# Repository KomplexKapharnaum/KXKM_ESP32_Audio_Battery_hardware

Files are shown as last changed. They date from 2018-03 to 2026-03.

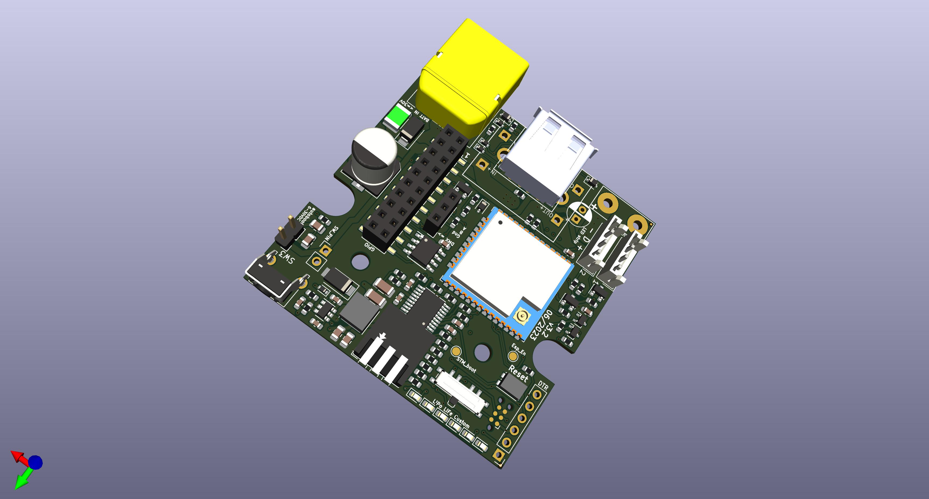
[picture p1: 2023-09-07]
Base_board/in-progress/KXKM_ESP32_battery_management_board.jpg

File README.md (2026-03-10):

# KXKM_ESP32_Audio_Battery_hardware

## Overview
Hardware workspace for the KXKM ESP32 battery + audio platform.
The repository groups KiCad design files for battery management and remote control boards.

## Installation
Prerequisites:
- KiCad 7/8 for schematic/project edits
- Git LFS is not required for the current tracked files

## Usage
Typical workflow:
1. Open the board project under `Base_board/v3.2/`.
2. Review schematic updates in `*.kicad_sch`.
3. Export manufacturing artifacts (Gerber/BOM) from KiCad when needed.

## Architecture
Main areas:
- `Base_board/`: battery management board revisions
- `Audio_board/`: audio-related board files
- `Remote_control_board/`: remote control board symbols/project config

## Testing & Quality
Recommended checks before commit:
- KiCad ERC/DRC on edited projects
- Diff review on `.kicad_sch`/`.kicad_pro` changes
- Ensure no local artifacts are tracked (`.DS_Store`, `*-backups/*.zip`)

## Performance & Optimization
Optimization focus:
- Keep schematic commits isolated from hygiene/meta commits
- Reduce noisy diffs by excluding generated/local backup files

## Security
Security notes:
- Avoid committing private manufacturing or supplier credentials
- Keep BOM/vendor metadata reviewable in plain text when possible

## Roadmap
Near-term:
- Finalize battery board v3.2 review cycle
- Validate remote control symbol table consistency

<!-- CHANTIER:AUDIT START -->
## Audit & Execution Plan (2026-03-10)

### Snapshot
- Priority: `P2`
- Tech profile: `other`
- Workflows: `yes`
- Tests: `yes`
- Debt markers: `0`
- Source files: `0`

### Corrections Prioritaires
- [ ] Optimisation ciblée perf/maintenabilité
- [ ] Ajouter/fiabiliser les commandes de vérification automatiques.
- [ ] Clore les points bloquants avant optimisation avancée.

### Optimisation
- [ ] Identifier le hotspot principal et mesurer avant/après.
- [ ] Réduire la complexité des modules les plus touchés.

### Mémoire chantier
- Control plane: `/Users/electron/.codex/memories/electron_rare_chantier`
- Repo card: `/Users/electron/.codex/memories/electron_rare_chantier/REPOS/KXKM_ESP32_Audio_Battery_hardware.md`

<!-- CHANTIER:AUDIT END -->

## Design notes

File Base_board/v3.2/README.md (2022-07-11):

To Panelize:
Install Kikit (at least the module, no need to install in kicad via PCM)

> kikit panelize -p panelizing_config.json KXKM_ESP32_battery_management_board.kicad_pcb PANEL/panel.kicad_pcb

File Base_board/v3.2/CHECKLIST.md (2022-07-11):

# Procédure prod 05/19
* Contrôle visuel dessus & dessous (polarité IC, diodes)
* Alim 6V 0.05A => check 3.3V à l'appui sur le bouton.
* Alim 24V 0.5A + constant current load => Flash STM32_HW_Test et exécuter tous les tests
//!!!!! CHANGER LES SEUILS !!
* Alim 6V 0.5A (ou injecte 3.3V direct) => Flash STM32 KXKM Batt Monitoring + assign ID + marquage
*       Flash ESP32 HW Test

# 23/07/19 troubleshooting prog. ESP
* =>> erreur Warning: Could not auto-detect Flash size (FlashID=0xffffff, SizeID=0xff), defaulting to 4MB : vérifier que IO6-IO11 ne sont pas en CC ; vérifier IO12 LOW (https://github.com/espressif/esptool/issues/263)
    Un bon coup de chaud sur l'ESP32 jusquà ce qu'il flotte et c'est reparti...

* Vérifier RX conn prog <-> ESP => rés. 1k
* Vérifier TX conn prog <-> ESP => connectés
* vérifier TX, RX pas en CC / pas en CC GND, 3.3V
* vérifier ESP32 BOOT, EN pas en CC GND, 3.3V
* vérifier 3.3V, GND ESP
* lancer prog et vérifier qu'il y a une pulse nég sur BOOT, nég sur EN

* Pas de court circuit entre - et + BATT, +3.3V
* Alimenter par Power In sous 6V (limite 100mA)
* Appuyer sur SW3 et vérifier la présence 3.3V tant qu'on tient SW3 appuyé.

# ESP32
* maintenir SW3 appuyé et brancher l'USB série /!\ vérifier CH430...
* insérer carte SD test
* Vérifier programmation et autoreset
* Flasher ESP32_HW_Test (/!\ pour la 1e programmation il faut peut être y aller à 115200 bps)
* Vérifier carte SD
* Vérifier sortie son

# STM32
* mettre sélecteur de batterie sur Custom
* brancher JLink device stm32f030f4 et vérifier que ça connecte bien
* Flasher STM32_HW_Test
* Vérifier jauge LED, détection bouton poussoir, sélecteur type batterie
* Vérifier activation sortie principale (+ mesure courant ?)
* Vérifier mesure tension batterie
* Vérifier activation ESP32 et communication
* Vérifier maintien 3.3V et coupure

# Programmation STM32
## Environnement
* Installer https://github.com/stm32duino/wiki/wiki/Getting-Started#boards-manager-concept > installe les outils, l'environnement etc pour STM32
* Récupérer le dépot git et pointer Arduino (Préférences > Emplacement du carnet de croquis)
* Sélectionner Type de carte : KXKM_STM32F030

## Upload
* Croquis > Exporter les binaires compilées
* mettre sélecteur de batterie sur Custom
* JlinkExe
** connect
** device stm32f030f4
** loadfile /home/tom/Nextcloud/KXKM/Module_Immobiles/firmware/Arduino/STM32_Blink/STM32_Blink.ino.KXKM_STM32F030F4.hex
** loadfile /home/tom/Nextcloud/KXKM/Module_Immobiles/firmware/Arduino/STM32_HW_test/STM32_HW_test.ino.KXKM_STM32F030F4.hex
** r
** g
* ou bien :
  cd <sketchName>
	JLinkExe -commanderscript STM32_flash.jlink

# 27/03/18 Tests
* régul 3.3V OK => 1A @6V IN, 800mA @ 25V IN
* activation régul par bouton OK
* programmation STM32 OK
* maintien et coupure du régul par STM32 OK
* ESP32 enable par STM32 OK
* ESP32 auto reset et programmation OK
* Load switch enable OK
* détection push button OK
* LED OK
* Sélecteur batterie OK
* communication ESP32 OK
* ESP32 carte SD OK
* ESP32 DAC OK
* emplacement ampli OK
* Load switch current à tester

# NOTES
* si SDA est tiré à la masse par l'ESP32 alors la programmation physique est impossible (drive BOOT par Q3B qui drive DTR par Q1A). Solution : Tirer ESP32_EN à la masse manuellement... et relacher au bon moment (alors que esptool dit Connecting...). Possible de le faire par le STM32 au reset ??? écoute sur le TX et active ESP32_EN au bon moment ?

# Troubleshooting
## Prog STM32
* Vérifier que le switch est bien en pos "Custom"

## carte SD
* Vérifier les soudures sur l'ESP

## Prog ESP32
* Resouder RN1, RN2
* Vérifier que l'ESP boote quand démarré par le STM32

## ESP32 always on
* Vérfier RN1

## Detection BP
* Vérifier diode Zener

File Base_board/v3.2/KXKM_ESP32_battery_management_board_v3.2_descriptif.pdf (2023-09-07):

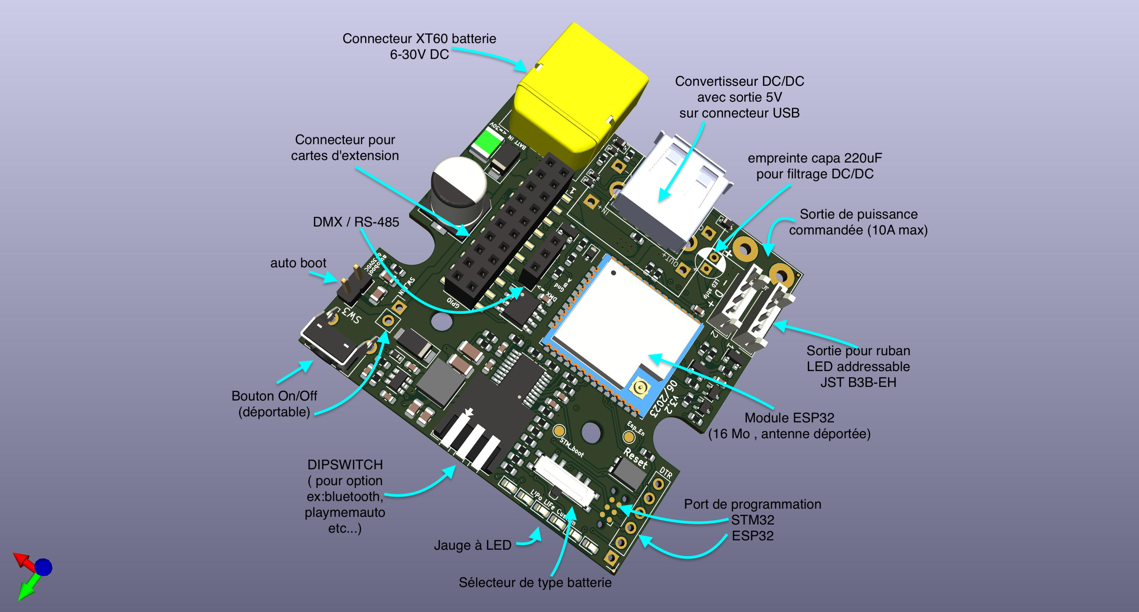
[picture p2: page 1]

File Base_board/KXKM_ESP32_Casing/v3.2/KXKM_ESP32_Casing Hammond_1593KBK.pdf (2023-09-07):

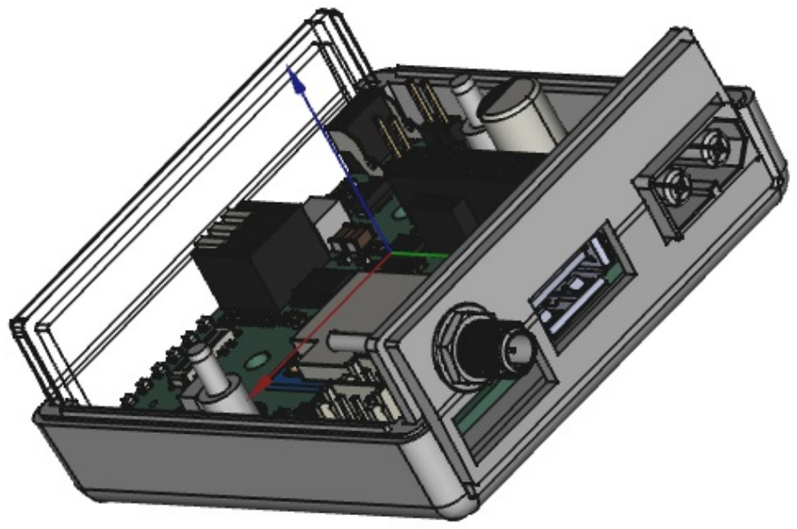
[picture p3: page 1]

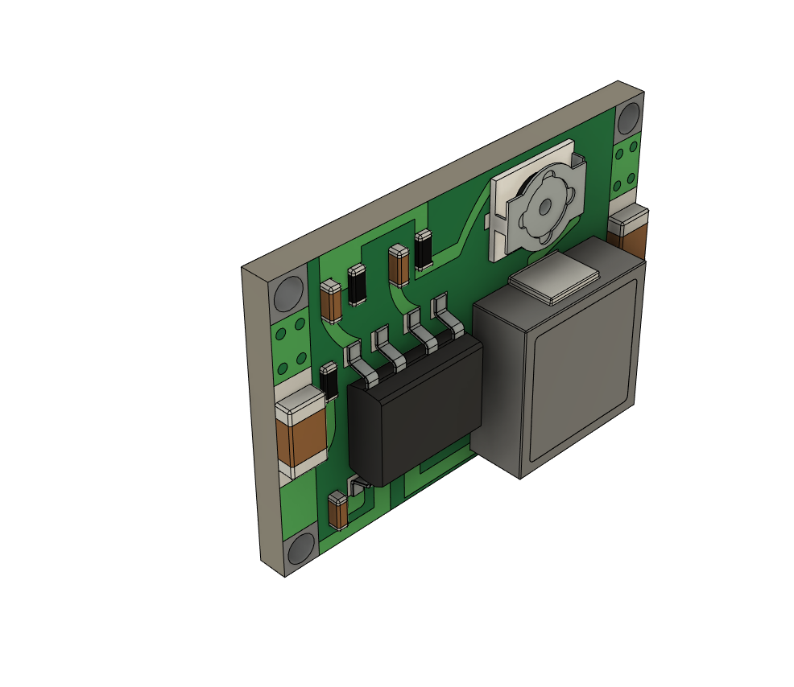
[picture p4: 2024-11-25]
Base_board/v3.2/mini-360-mp2307-1/MIni_1.png

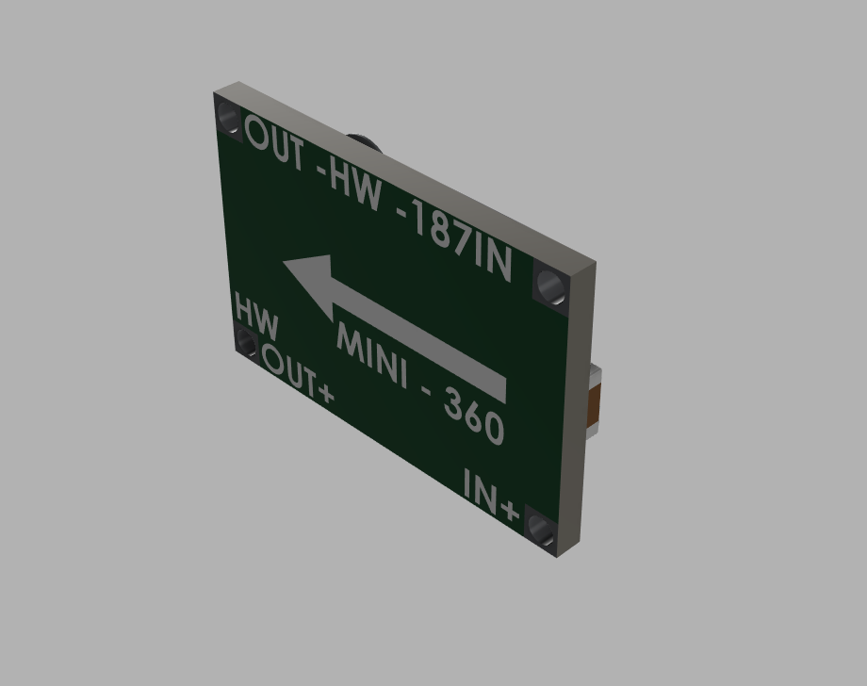
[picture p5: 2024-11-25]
Base_board/v3.2/mini-360-mp2307-1/MIni_4.png

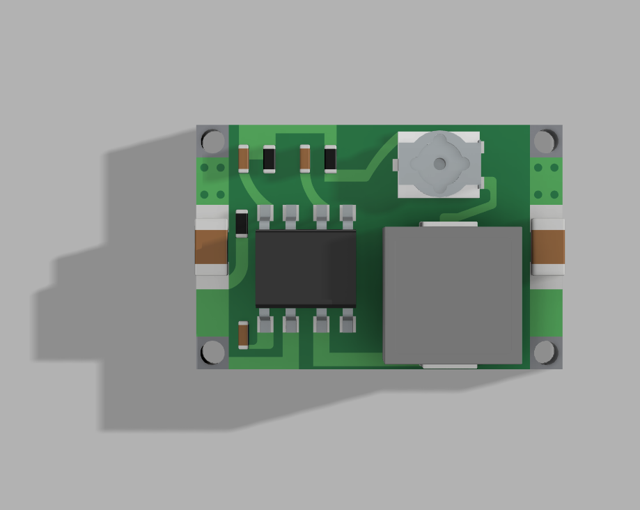
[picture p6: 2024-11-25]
Base_board/v3.2/mini-360-mp2307-1/MIni-2.png

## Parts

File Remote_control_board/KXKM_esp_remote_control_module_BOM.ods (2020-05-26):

Source: | C:\Users\utilisateur\Documents\KXKM\Git\KXKM_ESP32_Audio_Battery_hardware\Remote_control_board\KXKM_esp_remote_control_module.sch
Date: | 26/02/2020 17:42:19
Tool: | Eeschema (5.0.0)
Generator: | C:\Program Files\KiCad\bin\scripting\plugins/bom_csv_grouped_by_value.py
Component Count: | 21
Individual Components:
Item | Qty per board | Reference(s) | Value | Link | LibPart | Footprint
Capacitor | 2 | C1, C3 | 47n | https://fr.farnell.com/vishay/k473k20x7rh53h5/condensateur-47nf-100v-10-x7r/dp/3549756 | Device:C_Small | Capacitor_THT:C_Disc_D4.3mm_W1.9mm_P5.00mm
Capacitor | 1 | C2 | 4.7n | https://fr.farnell.com/vishay/k472k10x7rf5uh5/condensateur-4700pf-50v-10-x7r/dp/2860131 | Device:C_Small | Capacitor_THT:C_Disc_D4.3mm_W1.9mm_P5.00mm
Capacitor | 1 | C4 | 0.1u | https://fr.farnell.com/vishay/k104k15x7rf53l2/condensateur-0-1-f-50v-10-x7r/dp/1141775 | Device:C_Small | Capacitor_THT:C_Disc_D3.0mm_W1.6mm_P2.50mm
Capacitor | 1 | C5 | 0.33u | https://fr.farnell.com/multicomp/mc0805b334k500a5-08mm/condensateur-0-33-f-50v-10-x7r/dp/2309021 | Device:C_Small | Capacitor_THT:C_Disc_D4.3mm_W1.9mm_P5.00mm
LED | 1 | D1 | LED | Std – Not mounted | Device:LED | LED_SMD:LED_0805_2012Metric_Pad1.15x1.40mm_HandSolder
Pin header | 2 | J1, J6 | Conn_01x03 | Not mounted | Connector_Generic:Conn_01x03 | Connector_PinHeader_2.54mm:PinHeader_1x03_P2.54mm_Vertical
Pin header | 1 | J2 | Conn_02x10_Odd_Even | https://fr.farnell.com/harwin/m20-8751042/conn-header-20-voies-2-rangees/dp/3225960 | Connector_Generic:Conn_02x10_Odd_Even | Connector_PinHeader_2.54mm:PinHeader_2x10_P2.54mm_Vertical_SMD
Pin header | 1 | J3 | Conn_02x10_Odd_Even | Not mounted / In stock | Connector_Generic:Conn_02x10_Odd_Even | Connector_PinSocket_2.54mm:PinSocket_2x10_P2.54mm_Vertical_SMD
Pin header | 2 | J4, J5 | GPIO_conn | Not mounted / In stock | Connector_Generic:Conn_01x10 | Connector_PinHeader_2.54mm:PinHeader_1x10_P2.54mm_Vertical
Solder jumper | 2 | JP1, JP2 | Solder_Open | ~ | Jumper:SolderJumper_2_Open | Jumper:SolderJumper-2_P1.3mm_Open_TrianglePad1.0x1.5mm
Resistor | 1 | R1 | 22k | https://fr.farnell.com/multicomp/mcre000053/resistance-couche-carbon-125mw/dp/1700255 | Device:R | Resistor_THT:R_Axial_DIN0204_L3.6mm_D1.6mm_P5.08mm_Horizontal
Resistor | 1 | R2 | 220 | Std – Not mounted | Device:R | Resistor_SMD:R_0805_2012Metric_Pad1.15x1.40mm_HandSolder
Switch SPDT | 1 | SW1 | SW_SPDT | https://fr.farnell.com/nidec-copal/mfs101d-10-z/commut-glissiere-spdt-0-3a-30vdc/dp/2854841 | Switch:SW_SPDT | KXKM_esp_remote:Sw_MFS101D-10_1x03_P2.00mm
Switch push | 1 | SW2 | SW_Push | https://fr.farnell.com/c-k-components/pts645vh58-2lfs/commutateur-spst-0-05a-12vdc-tht/dp/2320088 | Switch:SW_Push | Button_Switch_THT:SW_Tactile_SPST_Angled_PTS645Vx58-2LFS
Current Sensor | 1 | U1 | HO10P-P-SP33 | https://fr.farnell.com/lem/ho-10-p-sp33/capteur-courant-10a-3-14vdc-3/dp/2664205?st=HO10P | KXKM_esp_remote_control_module:HO10P-P-SP33 | KXKM_esp_remote:HO10PSP33
I2C extender | 1 | U3 | MCP23017_SP | https://fr.farnell.com/microchip/mcp23017-e-sp/16-bit-expander-i-o-i2c-i-f/dp/1332088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 | :MCP23017_SP-Interface_Expansion | Package_DIP:DIP-28_W7.62mm
Voltage regulator | 1 | U4 | L78L33_TO92 | https://fr.farnell.com/stmicroelectronics/l78l33abz-ap/regulateur-lineaire-3-3v-0-1a/dp/2849743 | Regulator_Linear:L78L33_TO92 | Package_TO_SOT_THT:TO-92_Inline
Additionnal component for testing
Current Sensor | 1 | CJMCU758 | CJMCU758 | https://fr.aliexpress.com/item/32790187550.html?src=google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

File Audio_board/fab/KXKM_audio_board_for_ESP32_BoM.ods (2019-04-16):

KXKM – Audio DAC for ESP32 module
v1.0 – 04/2019
Reference | Qty | Value | Package | Link CN | Price (Qty 100) | Link Farnell | Price | Link RS | Price | Link Mouser | Commande production | Price | Link DGK | Price
C1 | 1 | DNP/0.1uF | C_0603_1608Metric | std
C10,C9 | 2 | 2.2uF,25V | C_0603_1608Metric | https://lcsc.com/product-detail/Multilayer-Ceramic-Capacitors-MLCC-SMD-SMT_muRata_GRM188R61E225KA12D_2-2uF-225-10-25V_C77047.html | 0,0254
C13,C12 | 2 | 2.2nF/C0G | C_0603_1608Metric | https://lcsc.com/product-detail/Multilayer-Ceramic-Capacitors-MLCC-SMD-SMT_2-2nF-222-5-50V_C107043.html | 0,0243
C14 | 1 | 10uF,50V | C_1206_3216Metric | https://lcsc.com/product-detail/Multilayer-Ceramic-Capacitors-MLCC-SMD-SMT_SAMSUNG_CL31A106KBHNNNE_10uF-106-10-50V_C13585.html | 0,0668
C2 | 1 | DNP/10nF | C_0603_1608Metric | std
C3,C5 | 2 | 10uF,10V | C_0805_2012Metric | std
C4 | 1 | 1uF | C_0603_1608Metric | std
C8,C11,C7,C6 | 4 | 0.1uF | C_0603_1608Metric | std
FB1 | 1 | 60R@100M | L_0805_2012Metric | std
J1 | 1 | Conn_02x10_Odd_Even | PinHeader_2x10_P2.54mm_Vertical_SMD | TODO Aliexpress
J2 | 1 | AudioJack2_Ground | Jack_3.5mm_stereo_PJ-313D | https://lcsc.com/product-detail/Audio-Connectors_Straight-headphone-jack_C18167.html | 0,049
J3 | 1 | Conn_02x10_Odd_Even | PinSocket_2x10_P2.54mm_Vertical_SMD | DNP
R2,R1 | 2 | 470R,1% | R_0603_1608Metric | std
R3,R4 | 2 | 10k | R_0603_1608Metric | std
U1 | 1 | DNP/TPS79133DBVR | SOT-23-5
U2 | 1 | PCM5121 | TSSOP-28_4.4x9.7mm_P0.65mm |  |  |  |  |  |  | https://www.mouser.fr/ProductDetail/Texas-Instruments/PCM5121PWR | 2,24
U3 | 1 | Audio_amp_OEP30W | Audio_amp_OEP30W
U4 | 1 | Audio_amp_OEP30Wx2 | Audio_amp_OEP30Wx2

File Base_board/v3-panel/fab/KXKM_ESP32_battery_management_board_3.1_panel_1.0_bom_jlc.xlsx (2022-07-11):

Comment | Designator | Footprint | JLCPCB Part
BC847W | B2-Q2,B4-Q1,B8-Q1,B5-Q2,B3-Q1,B7-Q2,B1-Q2,B4-Q2,B6-Q2,B0-Q2,B1-Q1,B8-Q2,B2-Q1,B5-Q1,B0-Q1,B7-Q1,B6-Q1,B3-Q2 | SOT-323_SC-70 | C75568
SW_SP3T | B1-SW4,B4-SW4,B7-SW4,B2-SW4,B5-SW4,B6-SW4,B0-SW4,B3-SW4,B8-SW4 | SW_SP3T_PCM13 | C160878
Conn_02x10_Odd_Even | B7-J3,B5-J3,B4-J3,B0-J3,B1-J3,B6-J3,B2-J3,B3-J3,B8-J3 | PinSocket_2x10_P2.54mm_Vertical_SMD | C59981
Green | B2-D7,B0-D7,B2-D5,B3-D5,B3-D6,B1-D5,B2-D6,B5-D5,B4-D6,B0-D6,B7-D5,B8-D7,B8-D5,B1-D6,B7-D6,B6-D5,B8-D6,B5-D7,B1-D7,B6-D6,B3-D7,B7-D7,B4-D7,B5-D6,B0-D5,B4-D5,B6-D7 | LED_0603_1608Metric | C72043
470R | B1-R28,B4-R8,B4-R28,B6-R8,B3-R8,B5-R8,B8-R8,B0-R8,B1-R8,B7-R8,B2-R8,B8-R28,B6-R28,B3-R28,B5-R28,B2-R28,B7-R28,B0-R28 | R_0603_1608Metric | C23179
10k | B2-R3,B8-R3,B1-R19,B5-R6,B5-R37,B5-R18,B6-R6,B8-R6,B6-R17,B1-R20,B6-R11,B6-R35,B7-R37,B2-R37,B0-R35,B2-R19,B8-R18,B4-R11,B2-R6,B3-R21,B4-R6,B3-R18,B6-R4,B7-R17,B0-R5,B0-R11,B3-R5,B7-R21,B7-R11,B4-R4,B0-R4,B8-R20,B7-R3,B8-R37,B5-R11,B0-R18,B7-R6,B4-R3,B6-R3,B1-R11,B0-R21,B3-R20,B4-R18,B1-R6,B4-R35,B3-R3,B7-R19,B6-R5,B5-R5,B7-R18,B8-R4,B1-R17,B3-R37,B5-R20,B2-R11,B1-R5,B3-R19,B2-R17,B0-R3,B4-R5,B0-R37,B3-R6,B1-R37,B4-R20,B1-R21,B3-R4,B2-R4,B2-R35,B4-R17,B4-R37,B7-R4,B7-R35,B0-R19,B3-R35,B5-R3,B5-R35,B2-R20,B6-R21,B8-R21,B8-R19,B3-R11,B2-R21,B7-R20,B8-R17,B4-R19,B3-R17,B1-R35,B0-R20,B1-R3,B1-R18,B5-R19,B8-R11,B7-R5,B5-R17,B6-R19,B8-R35,B2-R18,B6-R20,B1-R4,B5-R21,B6-R37,B0-R17,B4-R21,B0-R6,B6-R18,B5-R4,B2-R5,B8-R5 | R_0603_1608Metric | C25804
100uF,50V | B7-C6,B2-C6,B0-C6,B1-C6,B3-C6,B4-C6,B8-C6,B6-C6,B5-C6 | CP_Elec_8x10 | C97812
SW_Push | B4-SW1,B0-SW1,B7-SW1,B1-SW1,B6-SW1,B3-SW1,B2-SW1,B5-SW1,B8-SW1 | SW_SPST_KMR2 | C128941
0R | B5-R31,B6-R31,B7-R31,B8-R31,B2-R31,B3-R31,B1-R31,B4-R31,B0-R31 | R_0603_1608Metric | C21189
1k | B6-R23,B7-R23,B5-R2,B6-R2,B3-R2,B3-R23,B2-R23,B2-R2,B7-R2,B8-R2,B8-R23,B0-R23,B1-R2,B5-R23,B4-R2,B4-R23,B0-R2,B1-R23 | R_0603_1608Metric | C21190
22k | B2-R38,B1-R33,B8-R38,B3-R36,B1-R38,B5-R33,B0-R38,B0-R33,B8-R33,B3-R33,B4-R38,B1-R36,B0-R36,B3-R34,B4-R33,B5-R38,B4-R36,B6-R33,B3-R38,B8-R34,B2-R33,B5-R36,B7-R38,B7-R33,B2-R34,B8-R36,B6-R38,B0-R34,B6-R36,B4-R34,B5-R34,B7-R36,B7-R34,B1-R34,B2-R36,B6-R34 | R_0603_1608Metric | C31850
Yellow | B8-D8,B6-D8,B1-D9,B7-D9,B8-D9,B2-D8,B1-D8,B0-D8,B3-D9,B2-D9,B5-D9,B6-D9,B0-D9,B3-D8,B7-D8,B4-D8,B4-D9,B5-D8 | LED_0603_1608Metric | C72038
MCP16331T-E/CH | B3-U3,B7-U3,B1-U3,B8-U3,B2-U3,B0-U3,B4-U3,B6-U3,B5-U3 | SOT-23-6 | C105695
SW_DIP_x03 | B7-SW2,B6-SW2,B0-SW2,B5-SW2,B4-SW2,B1-SW2,B2-SW2,B3-SW2,B8-SW2 | SW_DIP_SPSTx03_Piano_CTS_Series194-3MSTN_W7.62mm_P2.54mm | C319070
31.6k/1% | B6-R16,B0-R16,B4-R16,B3-R16,B1-R16,B1-R9,B4-R9,B8-R16,B5-R16,B6-R9,B5-R9,B7-R9,B3-R9,B2-R16,B7-R16,B2-R9,B0-R9,B8-R9 | R_0603_1608Metric | C25967
Conn_01x02 | B0-J5,B8-J5,B4-J5,B1-J5,B5-J5,B6-J5,B3-J5,B2-J5,B7-J5 | PinHeader_1x02_P2.54mm_Vertical | C124375
1nF | B6-C21,B5-C21,B2-C21,B1-C21,B7-C21,B3-C21,B0-C21,B8-C21,B4-C21 | C_0603_1608Metric | C1588
10k/1% | B5-R1,B8-R1,B5-R10,B2-R10,B3-R10,B6-R10,B0-R1,B7-R10,B0-R10,B6-R1,B4-R10,B4-R1,B1-R1,B1-R10,B2-R1,B3-R1,B8-R10,B7-R1 | R_0603_1608Metric | C25804
15uH,1.5A | B3-L1,B4-L1,B1-L1,B7-L1,B8-L1,B5-L1,B6-L1,B0-L1,B2-L1 | L_Taiyo-Yuden_NR-50xx | C206232
10uF/50V | B5-C4,B8-C4,B3-C5,B2-C4,B2-C5,B4-C5,B0-C5,B0-C4,B7-C5,B5-C5,B4-C4,B7-C4,B6-C5,B8-C5,B1-C5,B1-C4,B6-C4,B3-C4 | C_1206_3216Metric | C13585
0.5A/30V | B8-F1,B2-F1,B7-F1,B5-F1,B0-F1,B3-F1,B6-F1,B4-F1,B1-F1 | Fuse_1812_4532Metric | C269128
270k/1% | B7-R15,B6-R15,B2-R15,B5-R15,B1-R15,B0-R15,B3-R15,B4-R15,B8-R15 | R_0603_1608Metric | C22965
10uF | B6-C9,B5-C9,B2-C9,B4-C10,B7-C10,B1-C10,B0-C9,B8-C10,B3-C10,B2-C10,B8-C9,B6-C10,B4-C9,B1-C9,B5-C10,B0-C10,B3-C9,B7-C9 | C_0805_2012Metric | C440198
Conn_01x06 | B1-J1,B8-J1,B5-J1,B6-J1,B2-J1,B4-J1,B0-J1,B7-J1,B3-J1 | PinHeader_1x06_P2.54mm_Vertical | C37208
1N4148WT | B5-D1,B4-D12,B7-D15,B8-D1,B0-D1,B2-D15,B0-D4,B4-D4,B8-D12,B5-D4,B1-D15,B3-D1,B3-D4,B1-D4,B1-D12,B0-D15,B4-D15,B3-D15,B6-D12,B7-D1,B8-D4,B8-D15,B2-D4,B1-D1,B6-D15,B5-D12,B6-D1,B7-D12,B7-D4,B3-D12,B4-D1,B0-D12,B2-D12,B6-D4,B5-D15,B2-D1 | D_SOD-523 | C68948
0.1uF | B4-C2,B1-C7,B0-C22,B8-C23,B5-C23,B4-C7,B2-C2,B5-C22,B1-C23,B1-C24,B2-C7,B5-C2,B3-C23,B4-C24,B2-C3,B3-C2,B2-C24,B0-C7,B0-C23,B6-C24,B0-C3,B7-C7,B6-C23,B8-C7,B4-C23,B6-C7,B2-C23,B3-C7,B3-C24,B1-C3,B6-C2,B7-C3,B3-C3,B0-C2,B1-C2,B7-C24,B3-C22,B7-C2,B5-C7,B8-C24,B0-C24,B8-C22,B8-C3,B5-C24,B5-C3,B4-C22,B1-C22,B2-C22,B7-C23,B4-C3,B7-C22,B8-C2,B6-C3,B6-C22 | C_0603_1608Metric | C14663
10nF | B1-C26,B0-C26,B3-C26,B2-C26,B6-C26,B7-C26,B5-C26,B8-C26,B4-C26 | C_0603_1608Metric | C57112
1uF | B1-C1,B0-C1,B5-C1,B8-C11,B4-C1,B3-C1,B2-C11,B8-C1,B6-C11,B4-C11,B7-C11,B2-C1,B7-C1,B5-C11,B6-C1,B3-C11,B1-C11,B0-C11 | C_0603_1608Metric | C15849
1A/100V | B4-D11,B0-D11,B3-D11,B4-D3,B3-D3,B6-D11,B1-D11,B0-D3,B2-D11,B5-D11,B1-D3,B2-D3,B6-D3,B7-D11,B8-D3,B8-D11,B5-D3,B7-D3 | D_SMA | C14996
SW_Push | B8-SW3,B5-SW3,B4-SW3,B7-SW3,B0-SW3,B2-SW3,B1-SW3,B3-SW3,B6-SW3 | SW_Tactile_SPST_Angled_PTS645Vx58-2LFS_horiz_pads | C127680
USB_A | B7-J9,B6-J9,B0-J9,B2-J9,B1-J9,B3-J9,B8-J9,B4-J9,B5-J9 | USB_A_Female | C2345
20pF | B6-C8,B2-C8,B1-C8,B5-C8,B8-C8,B3-C8,B4-C8,B0-C8,B7-C8 | C_0603_1608Metric | C1648
2N7002 | B5-Q5,B3-Q6,B5-Q4,B7-Q6,B1-Q6,B4-Q5,B1-Q4,B3-Q5,B5-Q6,B2-Q4,B6-Q5,B8-Q4,B7-Q4,B1-Q5,B8-Q6,B0-Q6,B0-Q4,B2-Q6,B2-Q5,B4-Q6,B7-Q5,B6-Q6,B6-Q4,B8-Q5,B4-Q4,B0-Q5,B3-Q4 | SOT-23 | C8545
ESP32-WROOM | B8-U1,B4-U1,B3-U1,B5-U1,B2-U1,B1-U1,B7-U1,B6-U1,B0-U1 | ESP32-WROOM-32U | C328062
1k/1% | B6-R22,B1-R12,B5-R12,B2-R22,B0-R22,B8-R22,B3-R12,B4-R22,B1-R22,B3-R22,B5-R22,B7-R12,B7-R22,B8-R12,B6-R12,B0-R12,B2-R12,B4-R12 | R_0603_1608Metric | C21190
Zener/3V/300mW | B1-D13,B2-D13,B3-D14,B1-D2,B6-D14,B3-D13,B8-D14,B7-D2,B8-D13,B0-D13,B7-D13,B8-D2,B1-D14,B5-D13,B5-D2,B0-D14,B3-D2,B6-D13,B5-D14,B2-D2,B4-D14,B4-D13,B7-D14,B2-D14,B4-D2,B6-D2,B0-D2 | D_SOD-323 | C19869
SP3485EEN | B8-U2,B5-U2,B2-U2,B1-U2,B3-U2,B4-U2,B0-U2,B6-U2,B7-U2 | SOIC-8_3.9x4.9mm_P1.27mm | C668205
100R | B8-R25,B2-R27,B4-R24,B5-R27,B1-R27,B6-R26,B3-R24,B2-R26,B7-R25,B5-R24,B6-R25,B3-R27,B6-R24,B4-R25,B0-R26,B2-R24,B1-R26,B4-R26,B5-R26,B2-R25,B7-R24,B0-R24,B3-R26,B6-R27,B4-R27,B0-R27,B8-R27,B1-R25,B5-R25,B3-R25,B0-R25,B7-R27,B8-R26,B7-R26,B1-R24,B8-R24 | R_0603_1608Metric | C22775
47k | B1-R32,B0-R32,B6-R32,B8-R32,B4-R32,B2-R32,B7-R32,B5-R32,B3-R32 | R_0603_1608Metric | C25819
STM32F070F6P6 | B7-U7,B0-U7,B6-U7,B2-U7,B4-U7,B3-U7,B1-U7,B8-U7,B5-U7 | TSSOP-20_4.4x6.5mm_P0.65mm | C86951
Conn_01x04 | B8-J4,B4-J4,B1-J4,B0-J4,B2-J4,B7-J4,B6-J4,B5-J4,B3-J4 | PinSocket_1x04_P2.54mm_Vertical | C124378
BTS50080-1TEA | B4-U4,B5-U4,B0-U4,B3-U4,B8-U4,B6-U4,B1-U4,B2-U4,B7-U4 | TO-252-4 | C152393
120R | B1-R7,B8-R7,B7-R7,B4-R7,B2-R7,B3-R7,B5-R7,B0-R7,B6-R7 | R_0603_1608Metric | C114681
Conn_01x03 | B0-J6,B8-J6,B7-J6,B5-J6,B4-J6,B6-J6,B1-J6,B3-J6,B2-J6 | PinHeader_1x03_P2.54mm_Vertical | C429954
Red | B8-D10,B1-D10,B3-D10,B5-D10,B0-D10,B2-D10,B4-D10,B7-D10,B6-D10 | LED_0603_1608Metric | C2286

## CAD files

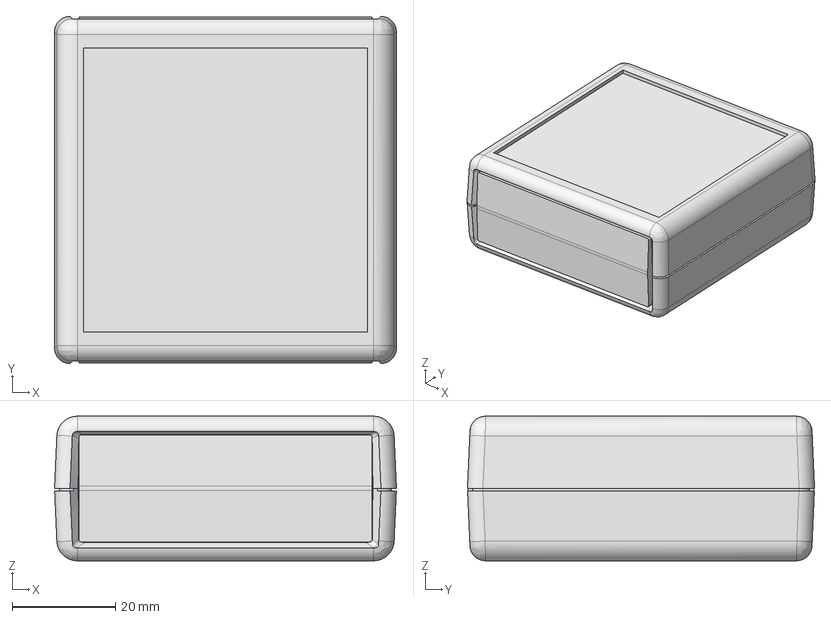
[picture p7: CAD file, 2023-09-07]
Base_board/KXKM_ESP32_Casing/1593KBK/1593K.stp
66.2 x 67.2 x 28.0 mm
1593K BOTTOM
1593K Top
1593K-L-P-Q-X-Y Flat endplate x 2
1593K-L-P-Q-X-Y Contoured Endplate x 2
1593K PCB

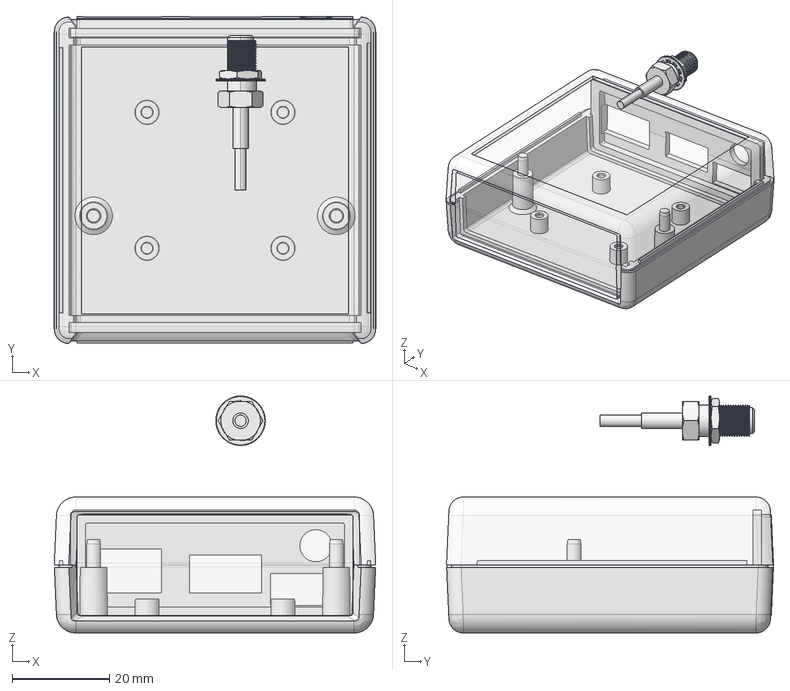
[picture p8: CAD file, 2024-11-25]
Base_board/KXKM_ESP32_Casing/v3.2/KXKM_ESP32_Casing Hammond_1593KBK 3.FCStd
66.2 x 67.4 x 48.8 mm
Corps
Connector_2
Washer
Nut
_593K_BOTTOM
_593K001_TOP
_593K003
_593K005
_593K006
_593K007

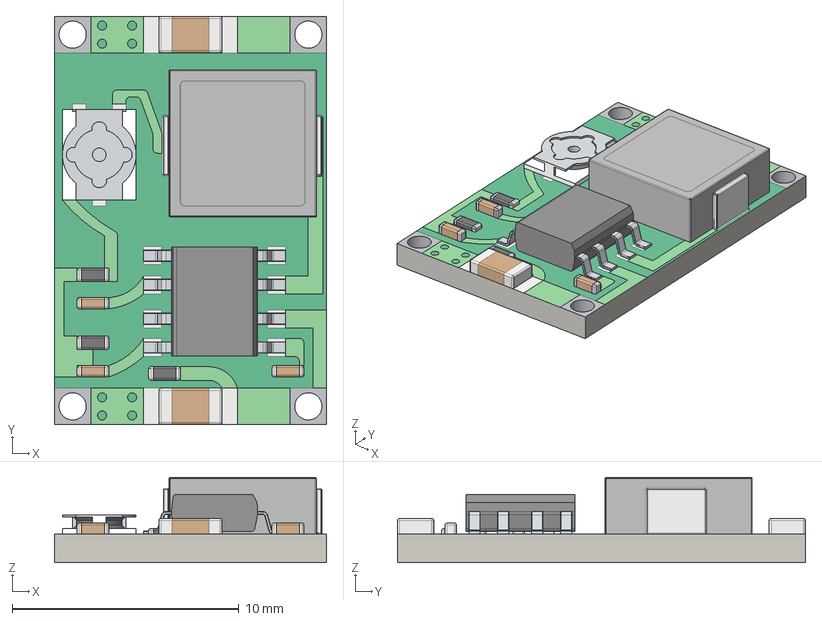
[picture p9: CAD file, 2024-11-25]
Base_board/v3.2/mini-360-mp2307-1/MIni - 360.step
12.0 x 18.0 x 3.75 mm

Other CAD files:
Base_board/KXKM_ESP32_Casing/1593KBK/1593K.igs

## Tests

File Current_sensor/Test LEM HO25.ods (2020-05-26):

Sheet: Feuille1
 |  | max ADC 3.3V | 4095
 |  |  | 2047,5 |  |  | LEM HO10 (5V)
Courant | Sortie ADC
-10,6 | 1692 |  |  |  |  | Courant | Sortie ADC
-5,3 | 1814 | 122 | -0,04344262295082 |  |  | 0 | 3000 | 2990 | 0
0 | 1937 | 123 |  |  |  | 0,5 | 3008 |  | 0,072727272727273
5,3 | 2064 | 127 | 23,0188679245283 |  |  | 1 | 3113 | 113 | 1,02727272727273
10,6 | 2188 | 124 |  |  |  | 2 | 3213 | 100 | 1,93636363636364
15,9 | 2312 |  |  |  |  | 3 | 3330 | 117 | 3
21,2 | 2436 |  |  |  |  | 4 | 3440 | 110 | 4
26,5 | 2560 |  |  |  |  | 5 | 3565 | 125 | 5,13636363636364
31,8 | 2684 |  |  |  | max value | 8,6 | 4095 |  | 9,95454545454546 |  | 0 | 3000
37,1 | 2808 |  |  |  |  | -1 | 2893 |  | -0,972727272727273 | 225 | 2 | 3225
42,4 | 2932 |  |  |  | 2962 | -2 | 2796 |  | -1,85454545454545 | 225 | 4 | 3450
47,7 | 3056 |  |  |  |  | -3 | 2700 |  | -2,72727272727273 | 250 | 6 | 3700
53 | 3180 |  |  |  |  | -4 | 2600 |  | -3,63636363636364 | 300 | 8 | 4000
58,3 | 3304 |  |  |  |  | -5 | 2500 |  | -4,54545454545455
63,6 | 3428 |  |  |  |  | -10 | 2020 |  | -8,90909090909091
68,9 | 3552 |  |  |  |  | -20 | 1010 |  | -18,0909090909091
74,2 | 3676 |  |  | 38,1976744186047
79,5 | 3800
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

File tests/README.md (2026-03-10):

# Smoke Tests

## Objectif
Valider un niveau minimal de qualité avant optimisation.

## Vérifications minimales
- Arborescence projet cohérente.
- README présent et à jour.
- Scripts/commandes principales documentés.
- Aucun artefact local suivi (`.DS_Store`, `*-backups/*.zip`, `~$*.xlsx`).
- Fichiers KiCad modifiés limités au périmètre du lot en cours.

## Critères de réussite
- Aucune erreur bloquante détectée sur les commandes de base.

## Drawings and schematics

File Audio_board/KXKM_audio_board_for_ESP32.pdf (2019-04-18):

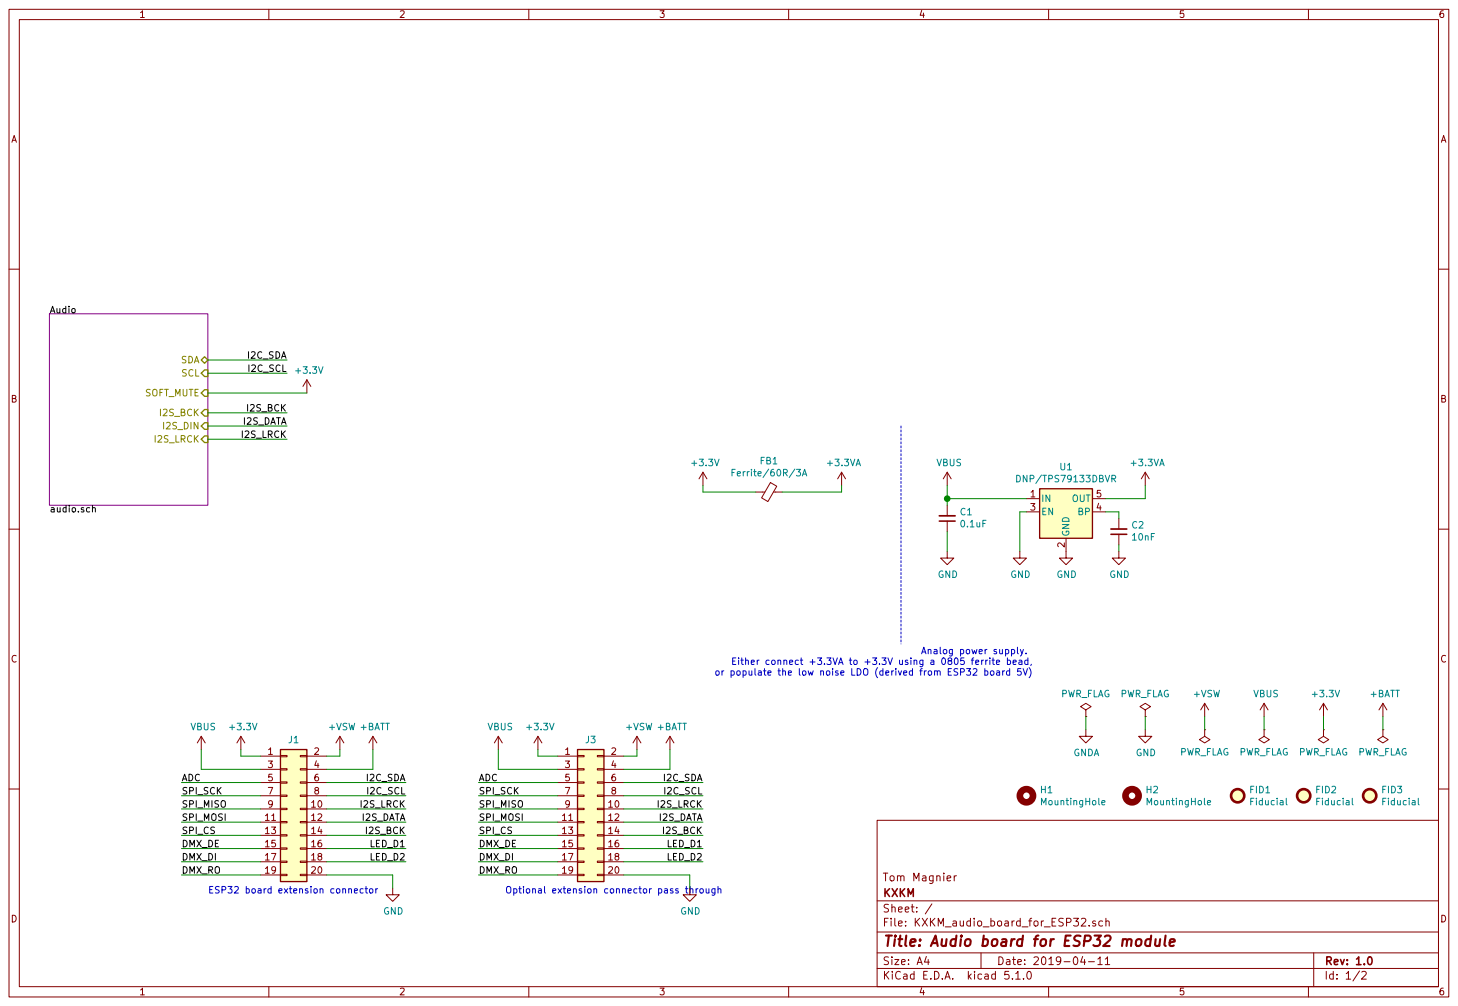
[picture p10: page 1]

2 EN 3 BP 4 OUT 5 U1 DNP/TPS79133DBVR

or populate the low noise LDO (derived from ESP32 board 5V) +3.3V

Either connect +3.3VA to +3.3V using a 0805 ferrite bead,

Tom Magnier
File: KXKM_audio_board_for_ESP32.sch Sheet: / KXKM

Id: 1/2 Title: Audio board for ESP32 module

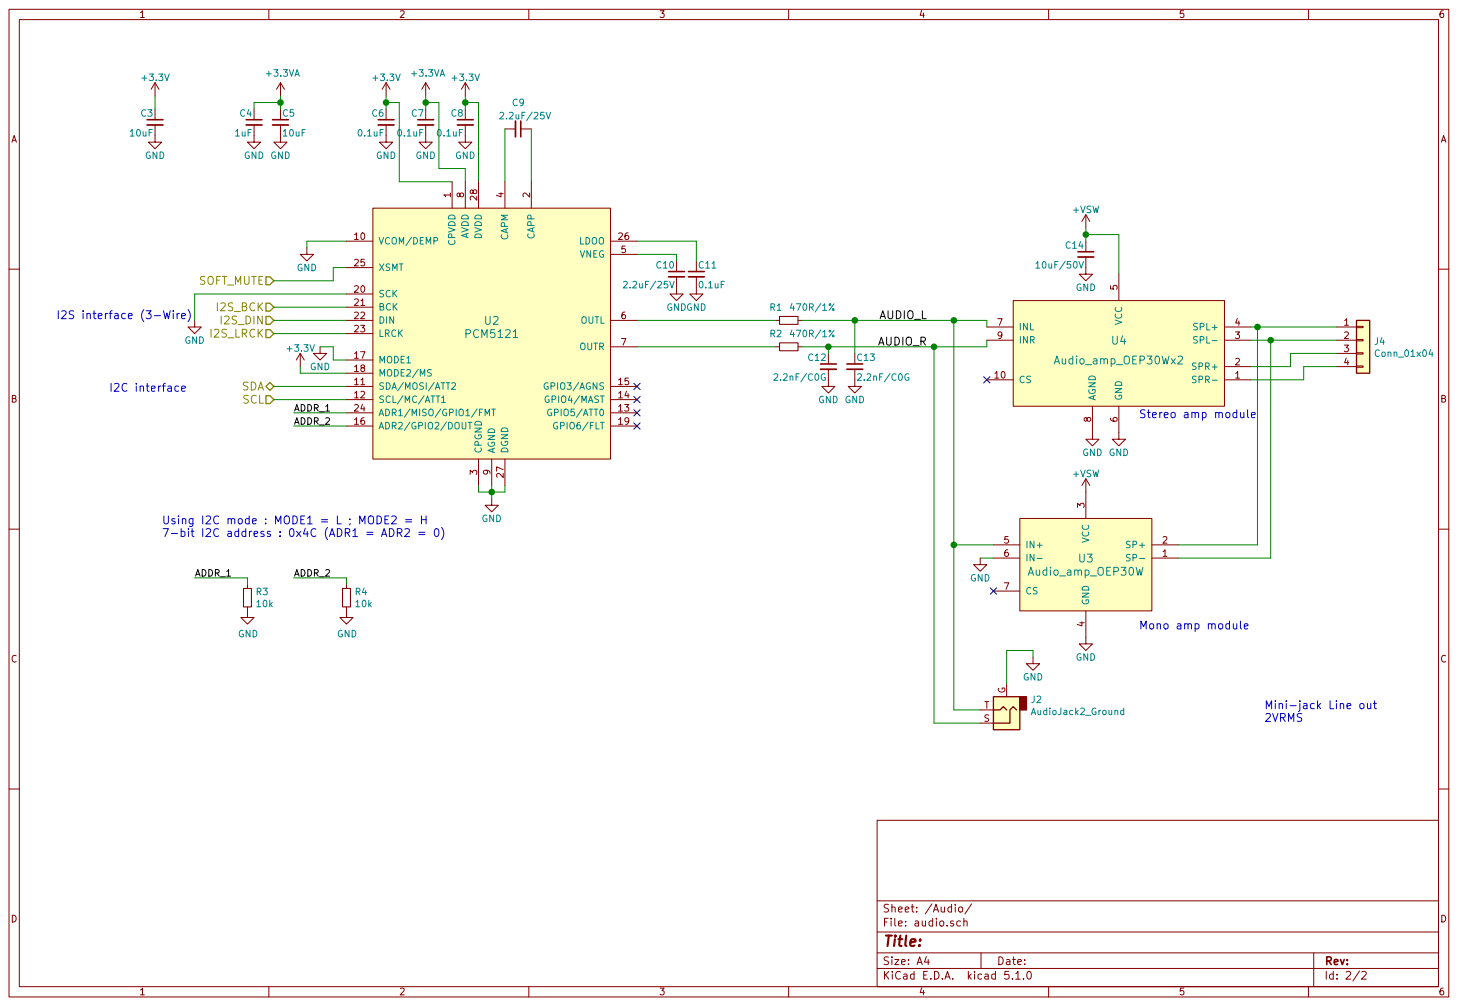
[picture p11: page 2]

1 VCOM/DEMP 10 SDA/MOSI/ATT2 11 SCL/MC/ATT1 12 GPIO5/ATT0 13 GPIO4/MAST 14 GPIO3/AGNS 15 ADR2/GPIO2/DOUT 16 MODE1 17 MODE2/MS 18 GPIO6/FLT 19 CAPP

4 VNEG 5 OUTL 6 OUTR 7 AVDD

Mini-jack Line out
2VRMS

Id: 2/2 Title: File: audio.sch Sheet: /Audio/

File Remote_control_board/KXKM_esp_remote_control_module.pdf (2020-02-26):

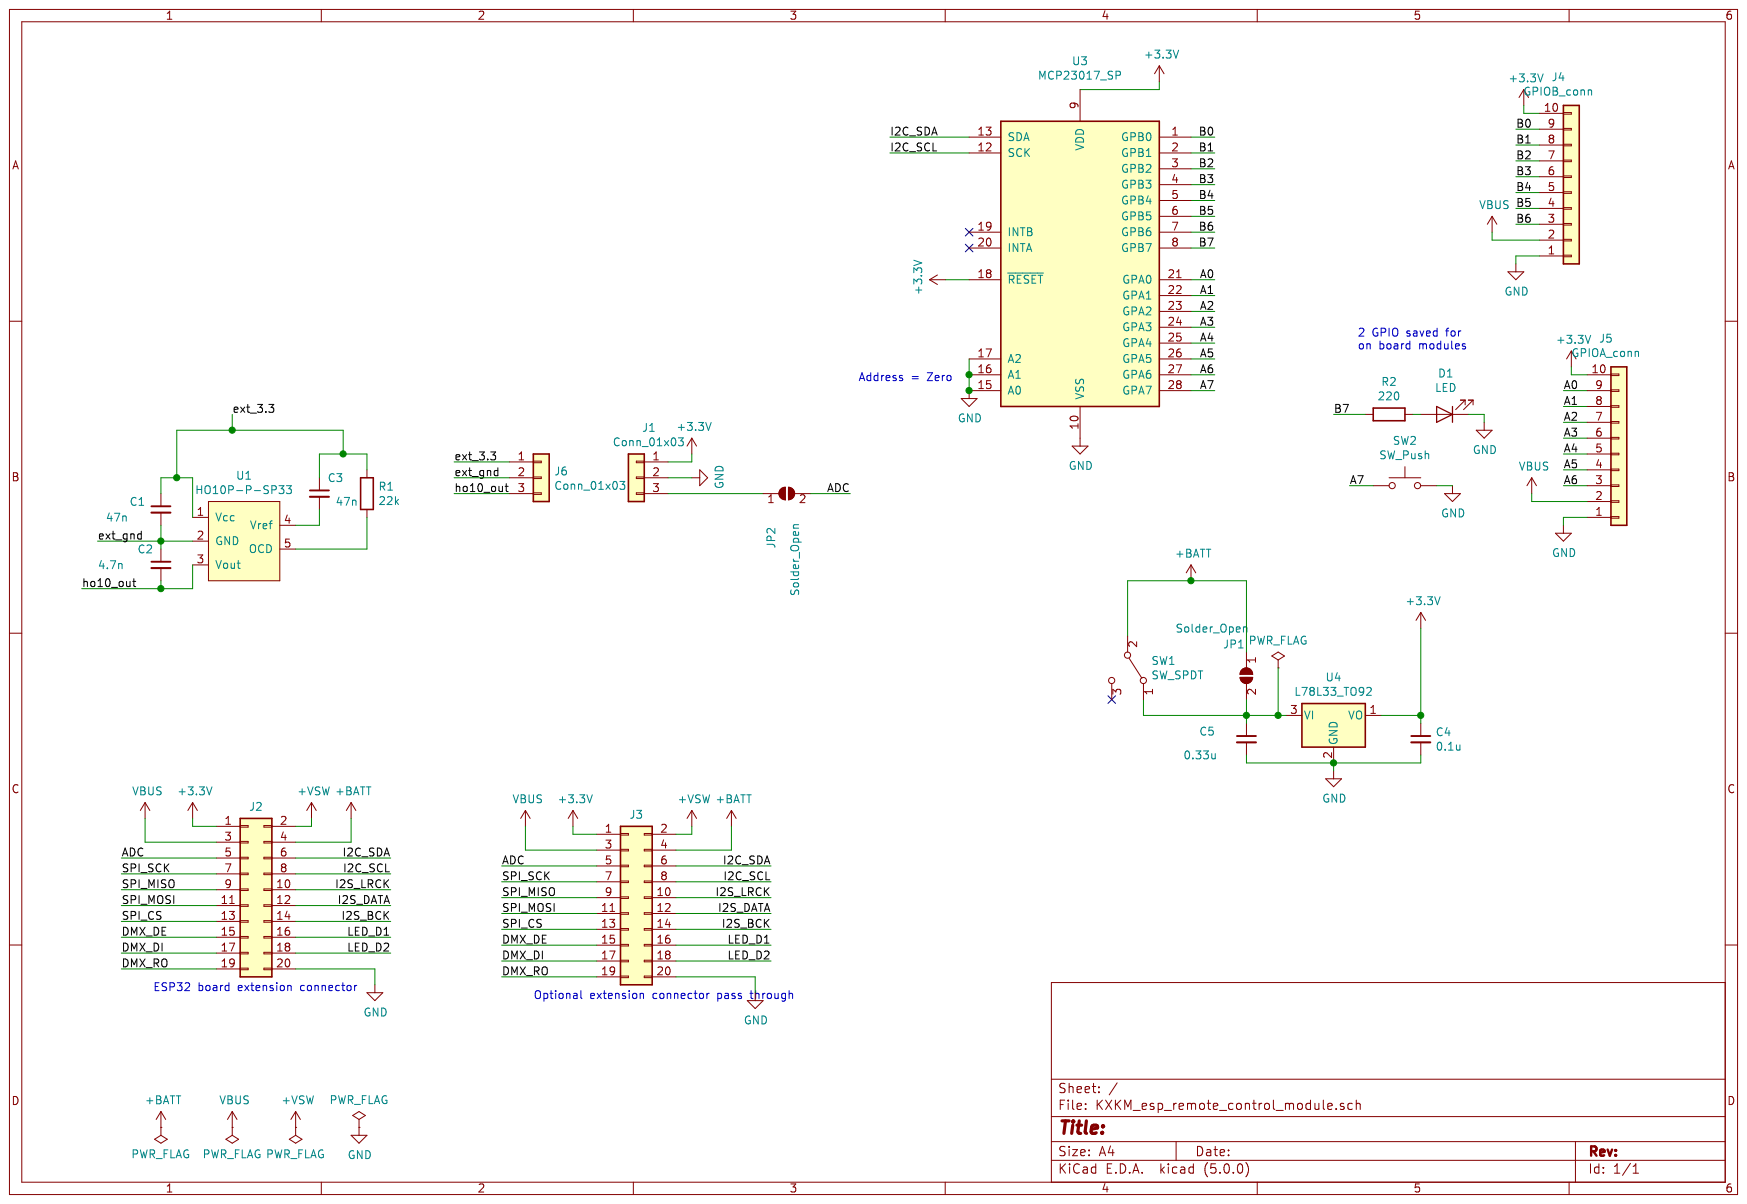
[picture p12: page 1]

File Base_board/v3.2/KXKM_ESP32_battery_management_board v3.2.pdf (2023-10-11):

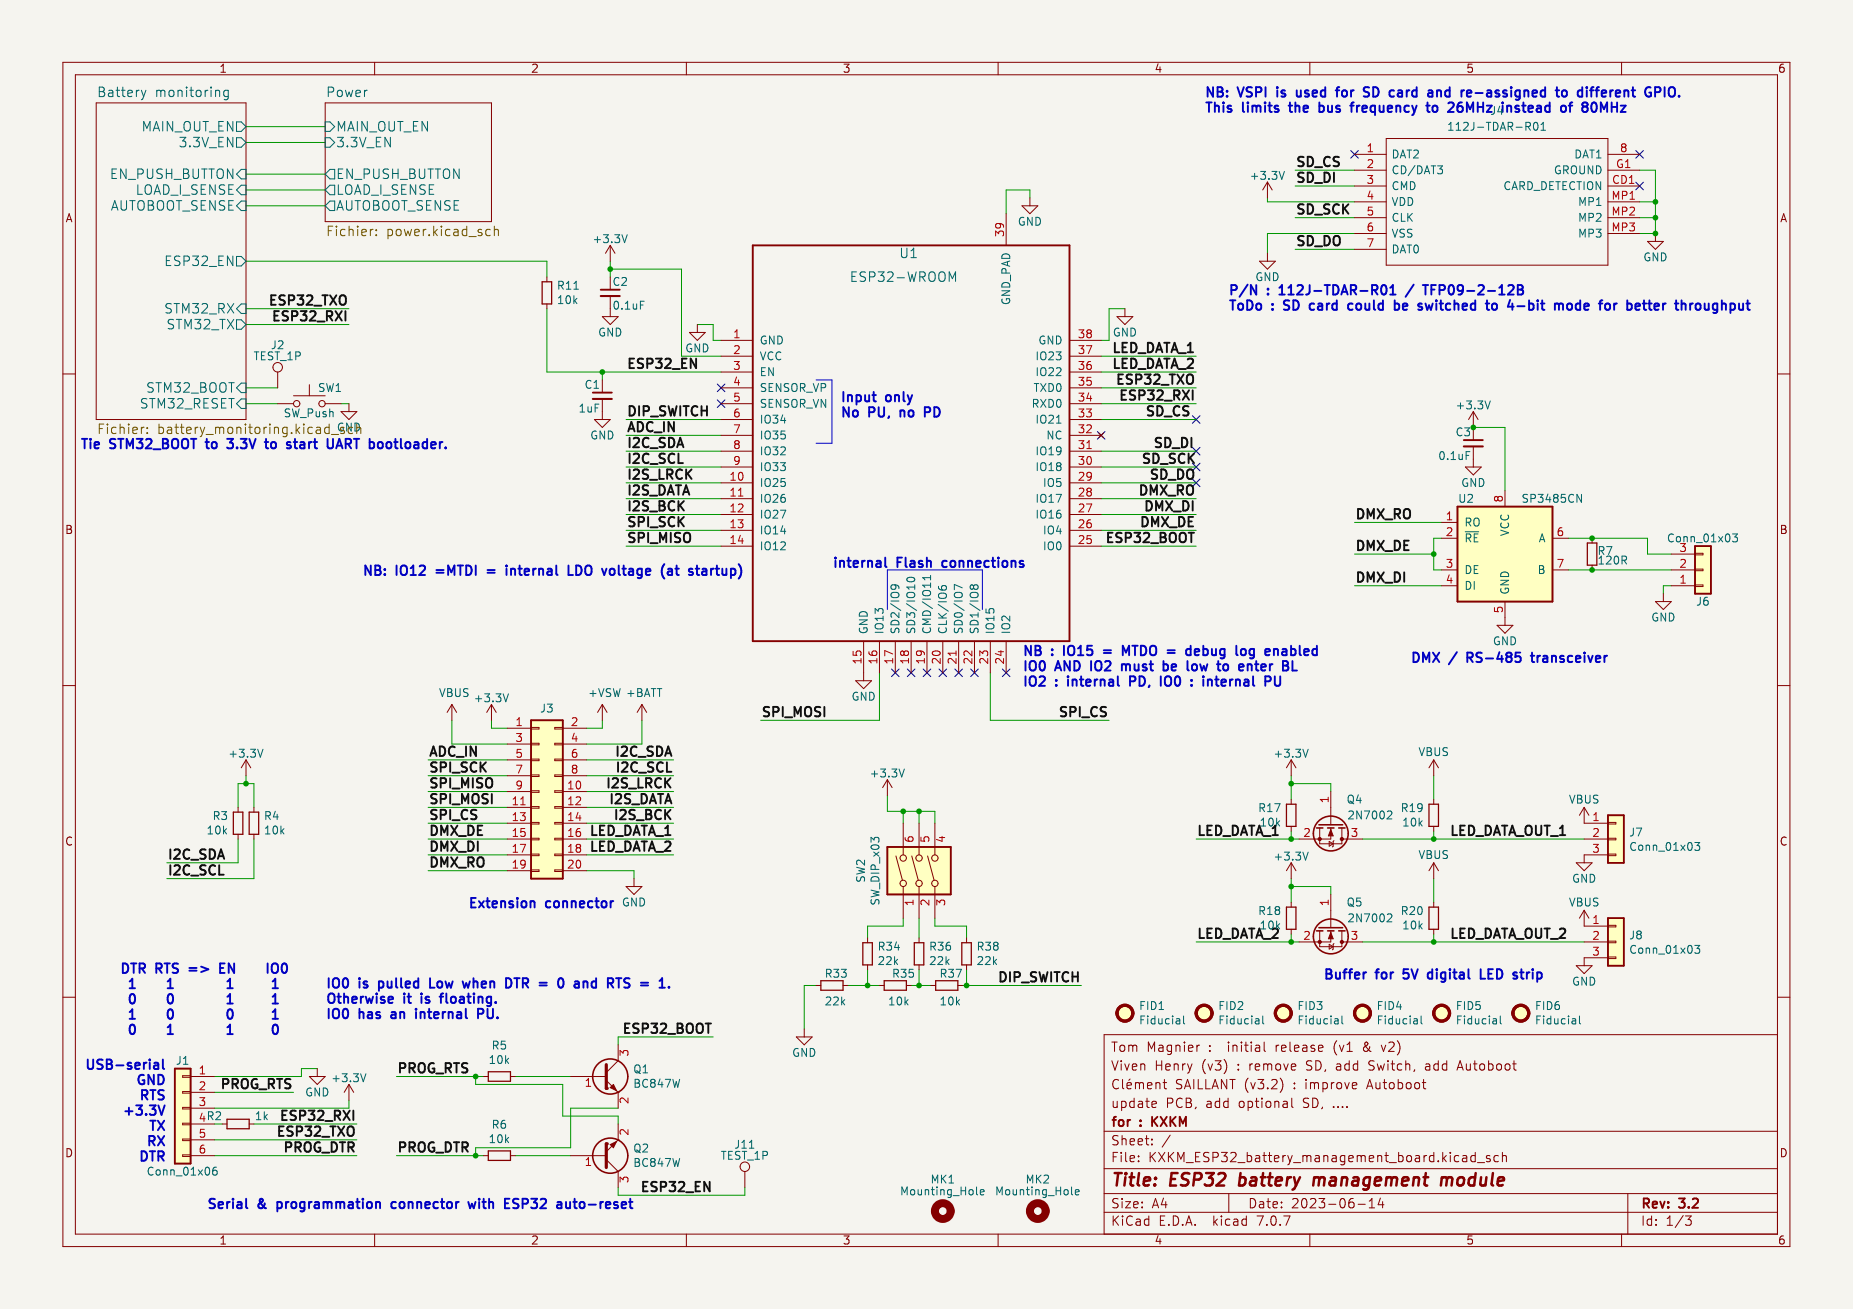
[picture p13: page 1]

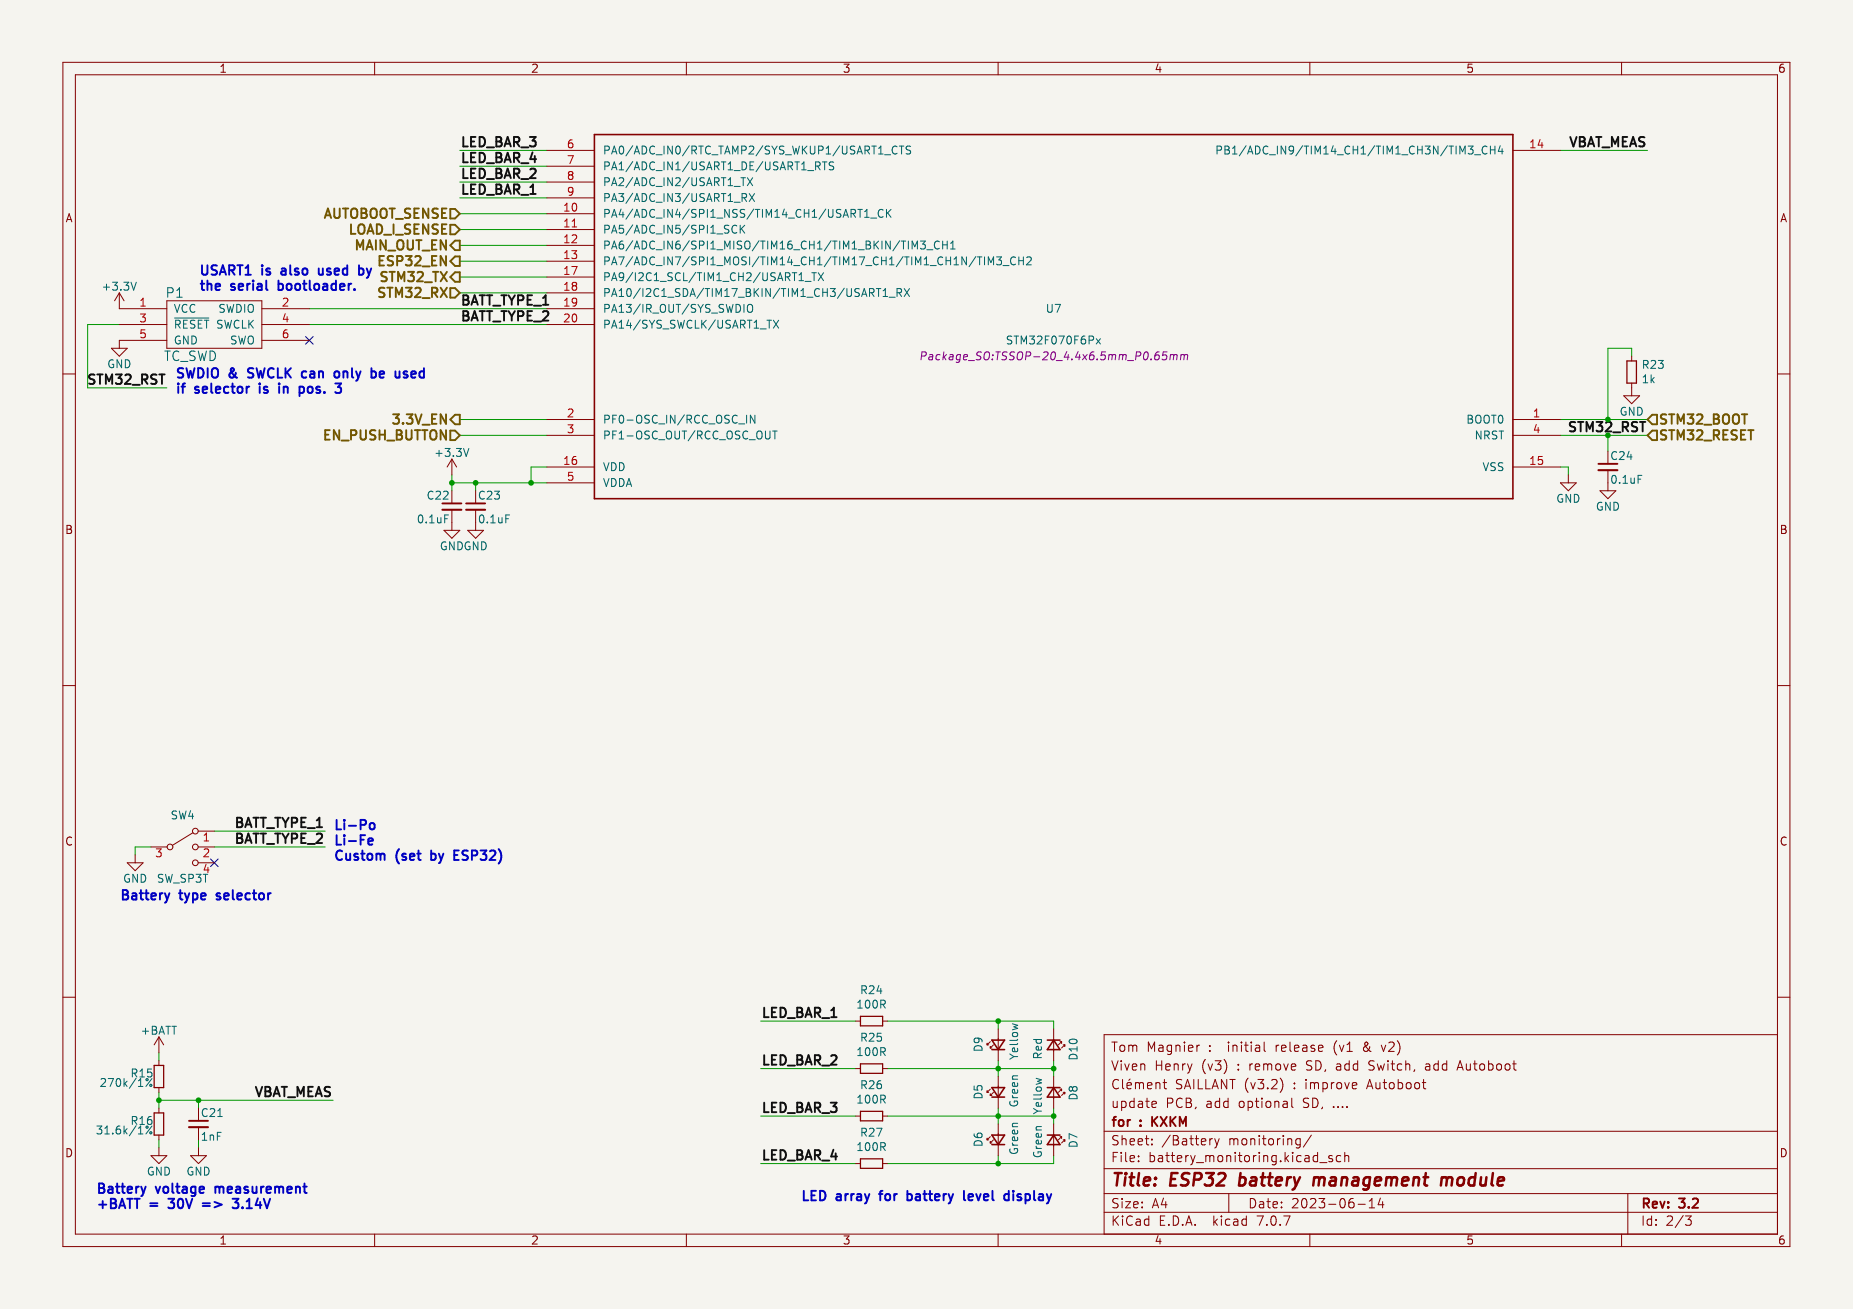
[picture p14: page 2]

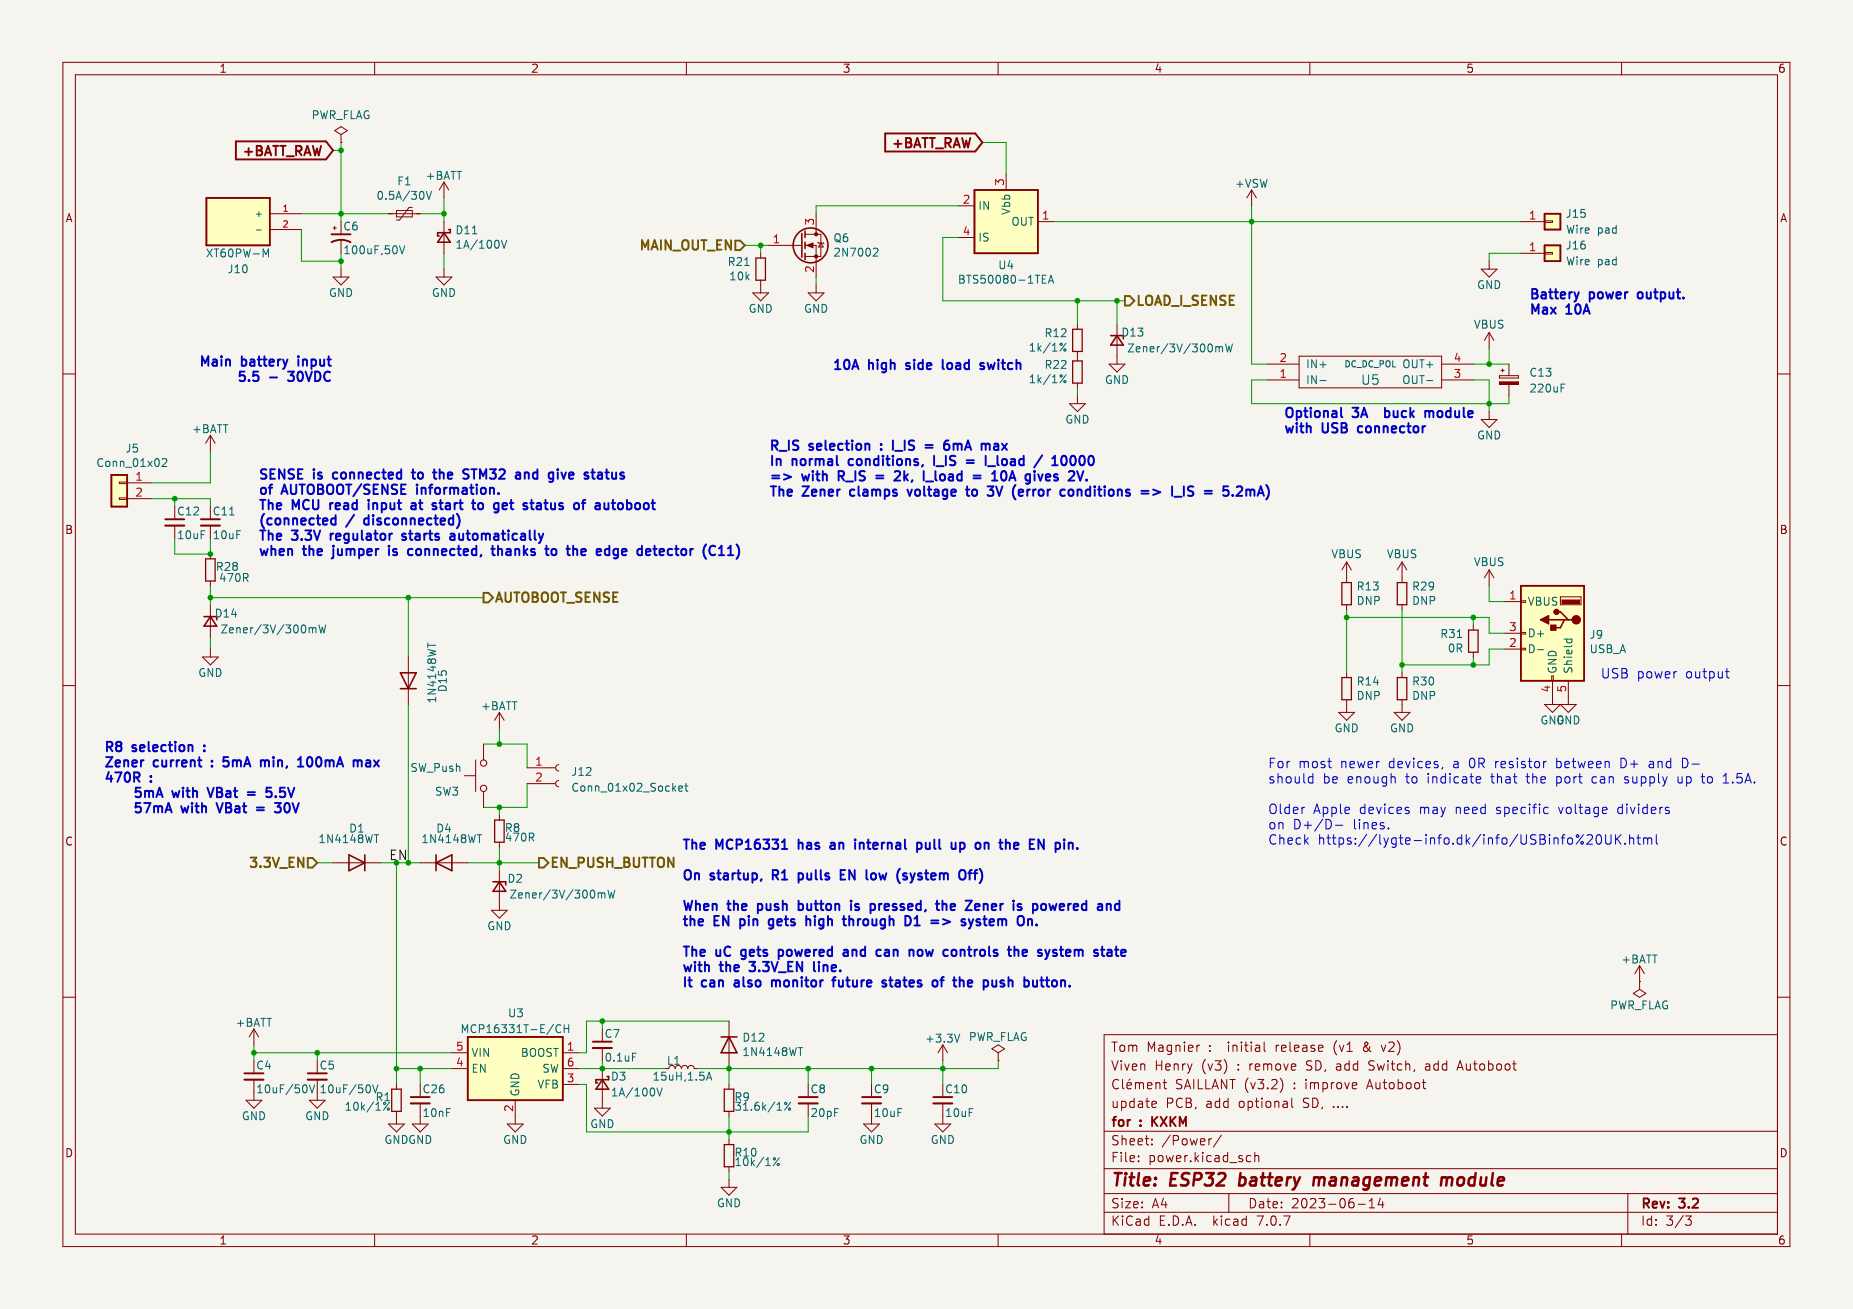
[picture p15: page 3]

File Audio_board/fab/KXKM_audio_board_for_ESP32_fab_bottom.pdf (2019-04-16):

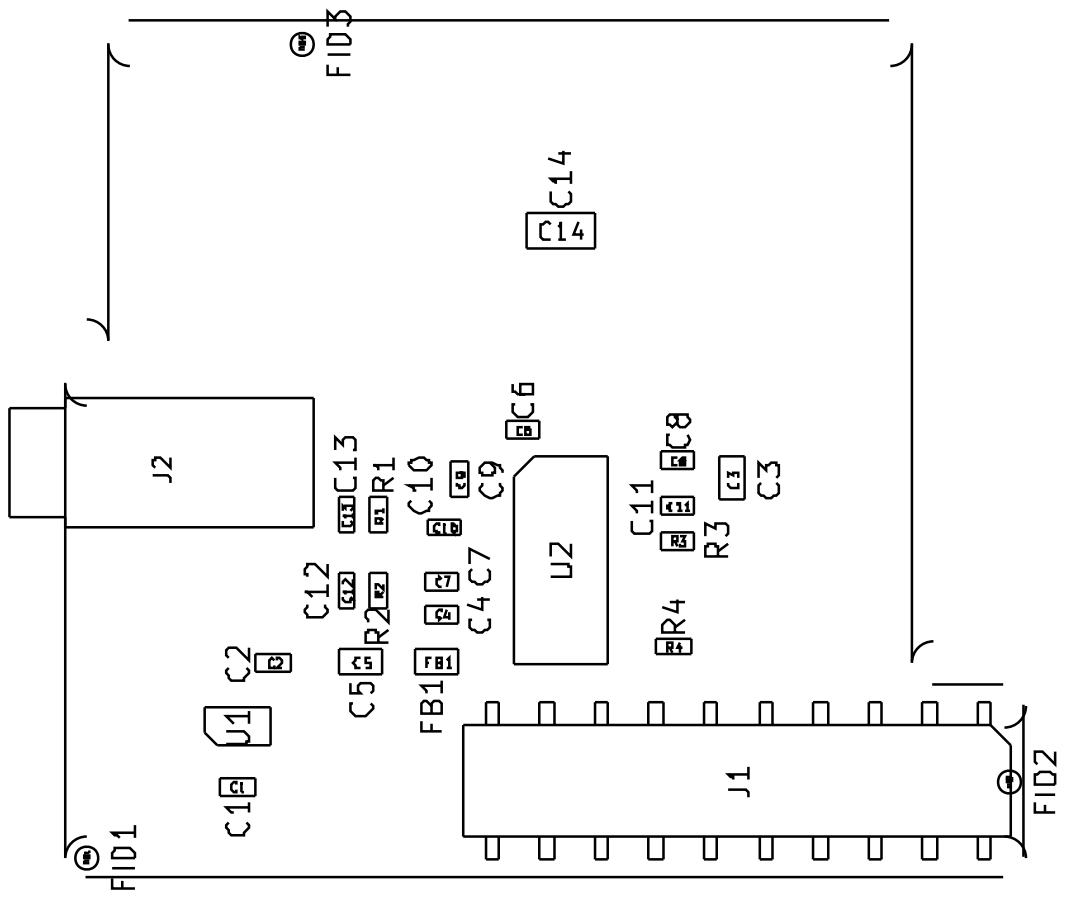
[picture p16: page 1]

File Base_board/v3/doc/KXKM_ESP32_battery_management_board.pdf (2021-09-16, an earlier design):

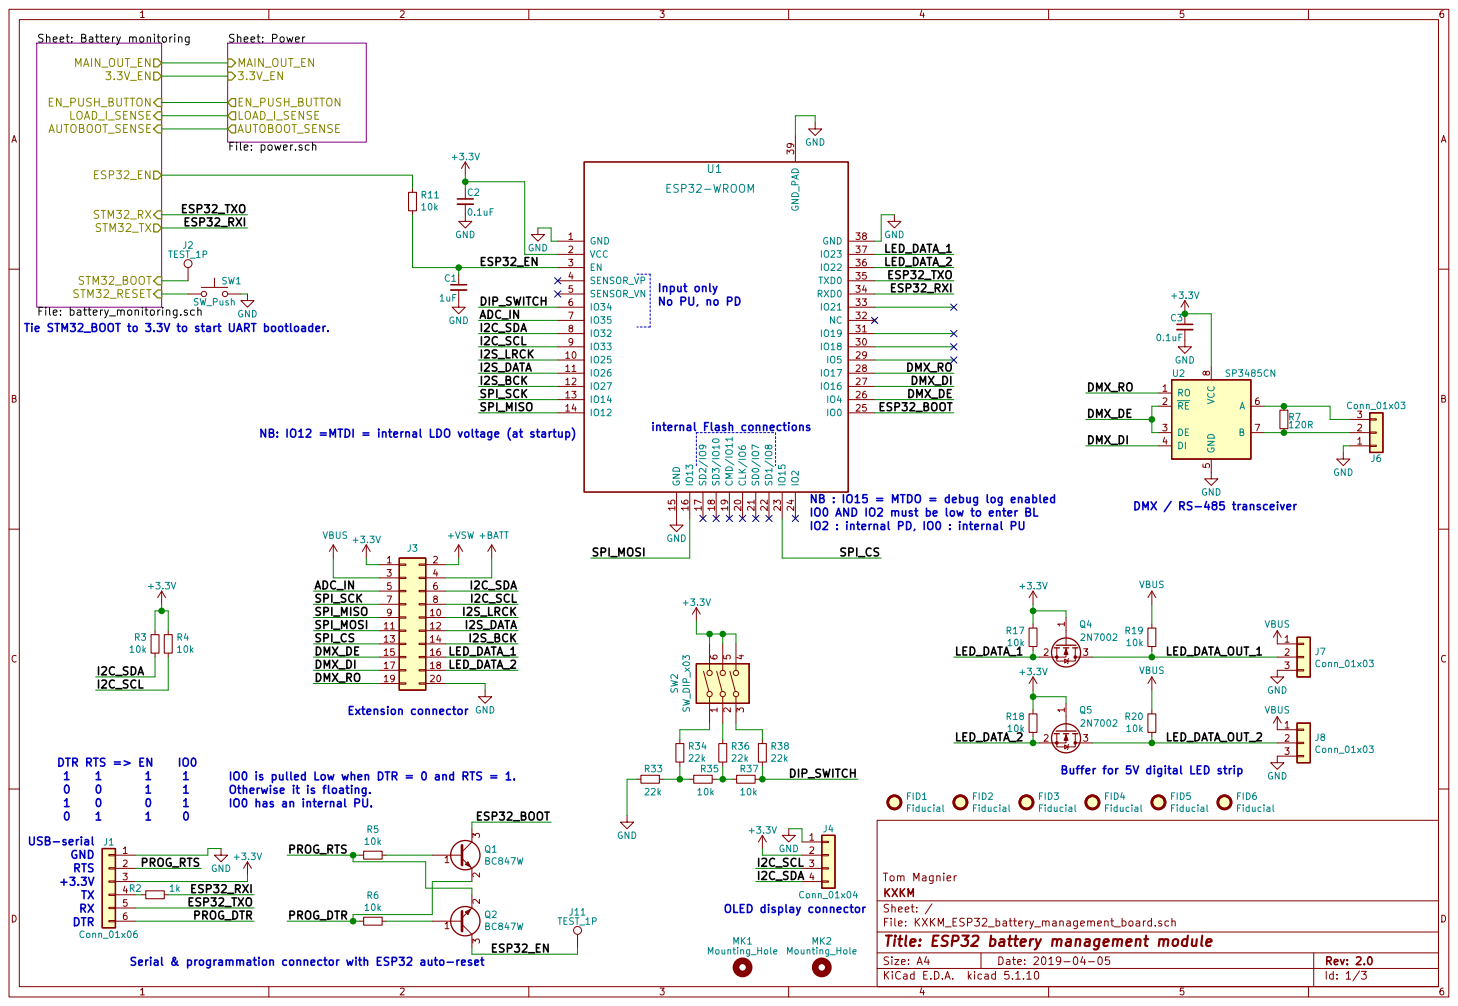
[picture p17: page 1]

STM32_BOOT
STM32_RESET
File: battery_monitoring.sch
Tie STM32_BOOT to 3.3V to start UART bootloader.

Input only

I2C_SCL
I2S_LRCK | | IO25 10
I2S_DATA | IO26 11 | DMX_RO
I2S_BCK | IO27 12 | DMX_DI

IO14 13 | DMX_DE

NB: IO12 =MTDI = internal LDO voltage (at startup)

internal Flash connections

NB : IO15 = MTDO = debug log enabled
IO0 AND IO2 must be low to enter BL
IO2 : internal PD, IO0 : internal PU

OLED display connector Extension connector

22k GND
Buffer for 5V digital LED strip IO0 is pulled Low when DTR = 0 and RTS = 1.
Otherwise it is floating.

Tom Magnier
File: KXKM_ESP32_battery_management_board.sch Sheet: / KXKM

ESP32_RXI

5 | ESP32_TXO

Id: 1/3 Title: ESP32 battery management module

Serial & programmation connector with ESP32 auto-reset

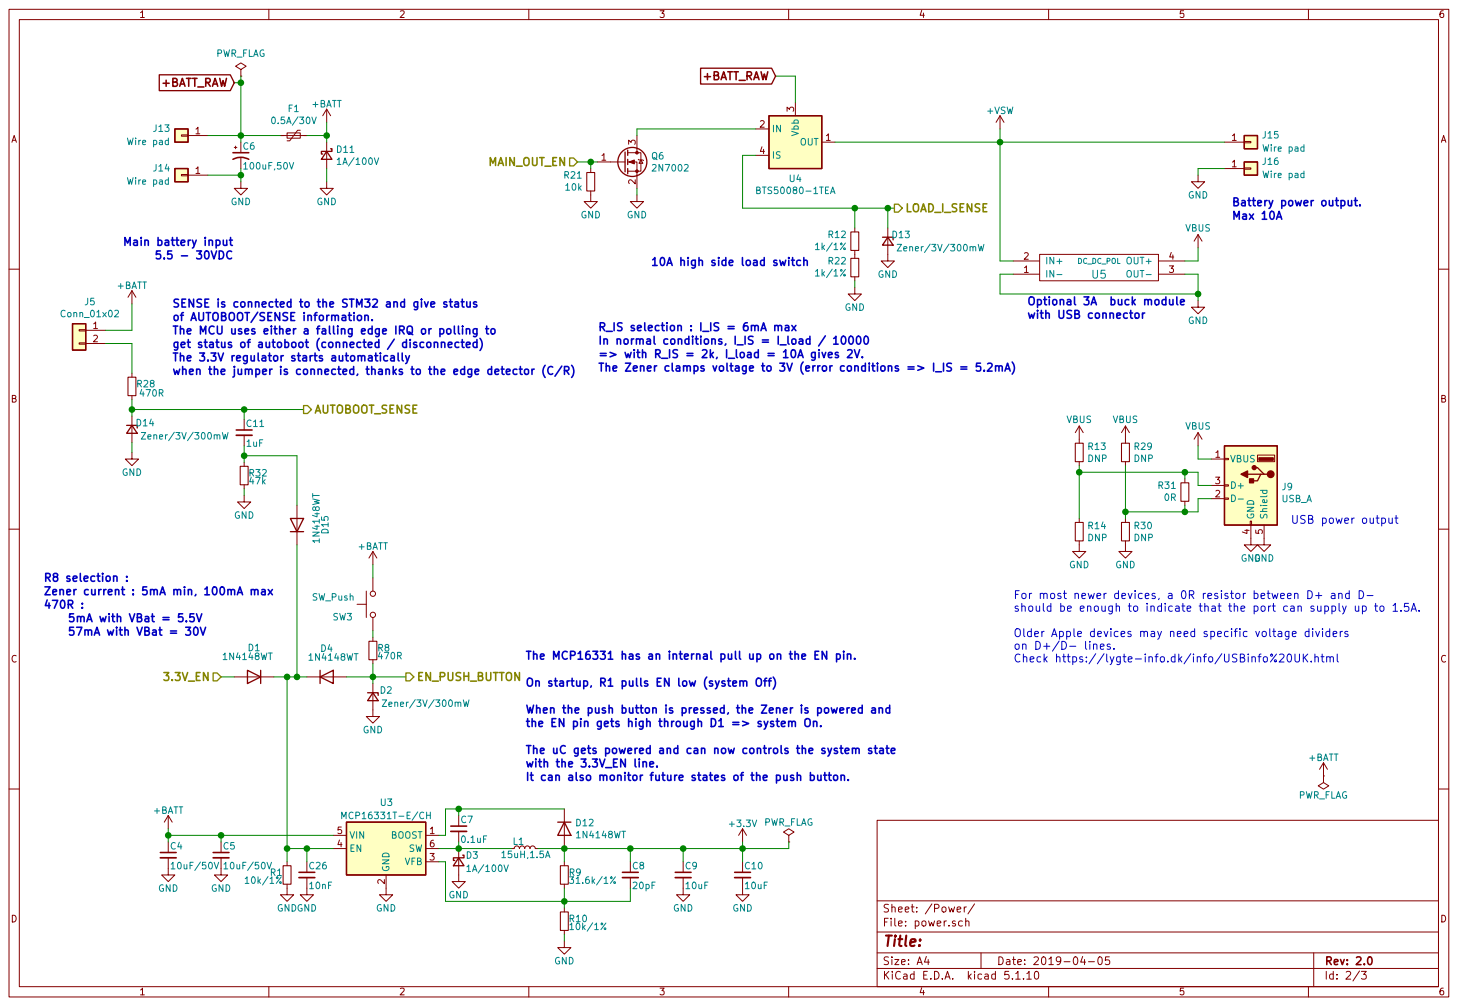
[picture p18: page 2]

10k D14Zener/3V/300mW
Battery power output. Max 10A Main battery input

10A high side load switch

SENSE is connected to the STM32 and give status
GND
of AUTOBOOT/SENSE information.
The MCU uses either a falling edge IRQ or polling to
get status of autoboot (connected / disconnected)
The 3.3V regulator starts automatically
when the jumper is connected, thanks to the edge detector (C/R)

In normal conditions, I_IS = I_load / 10000
=> with R_IS = 2k, I_load = 10A gives 2V.
The Zener clamps voltage to 3V (error conditions => I_IS = 5.2mA)

R8 selection : Zener current : 5mA min, 100mA max 470R :

For most newer devices, a 0R resistor between D+ and D-
should be enough to indicate that the port can supply up to 1.5A.

Older Apple devices may need specific voltage dividers
on D+/D- lines.
Check https://lygte-info.dk/info/USBinfo%20UK.html

The MCP16331 has an internal pull up on the EN pin.

On startup, R1 pulls EN low (system Off)

When the push button is pressed, the Zener is powered and
the EN pin gets high through D1 => system On.

The uC gets powered and can now controls the system state
with the 3.3V_EN line.
It can also monitor future states of the push button.

2 VFB 3 EN 4 VIN 5 SW 6 U3 MCP16331T-E/CH GND GND

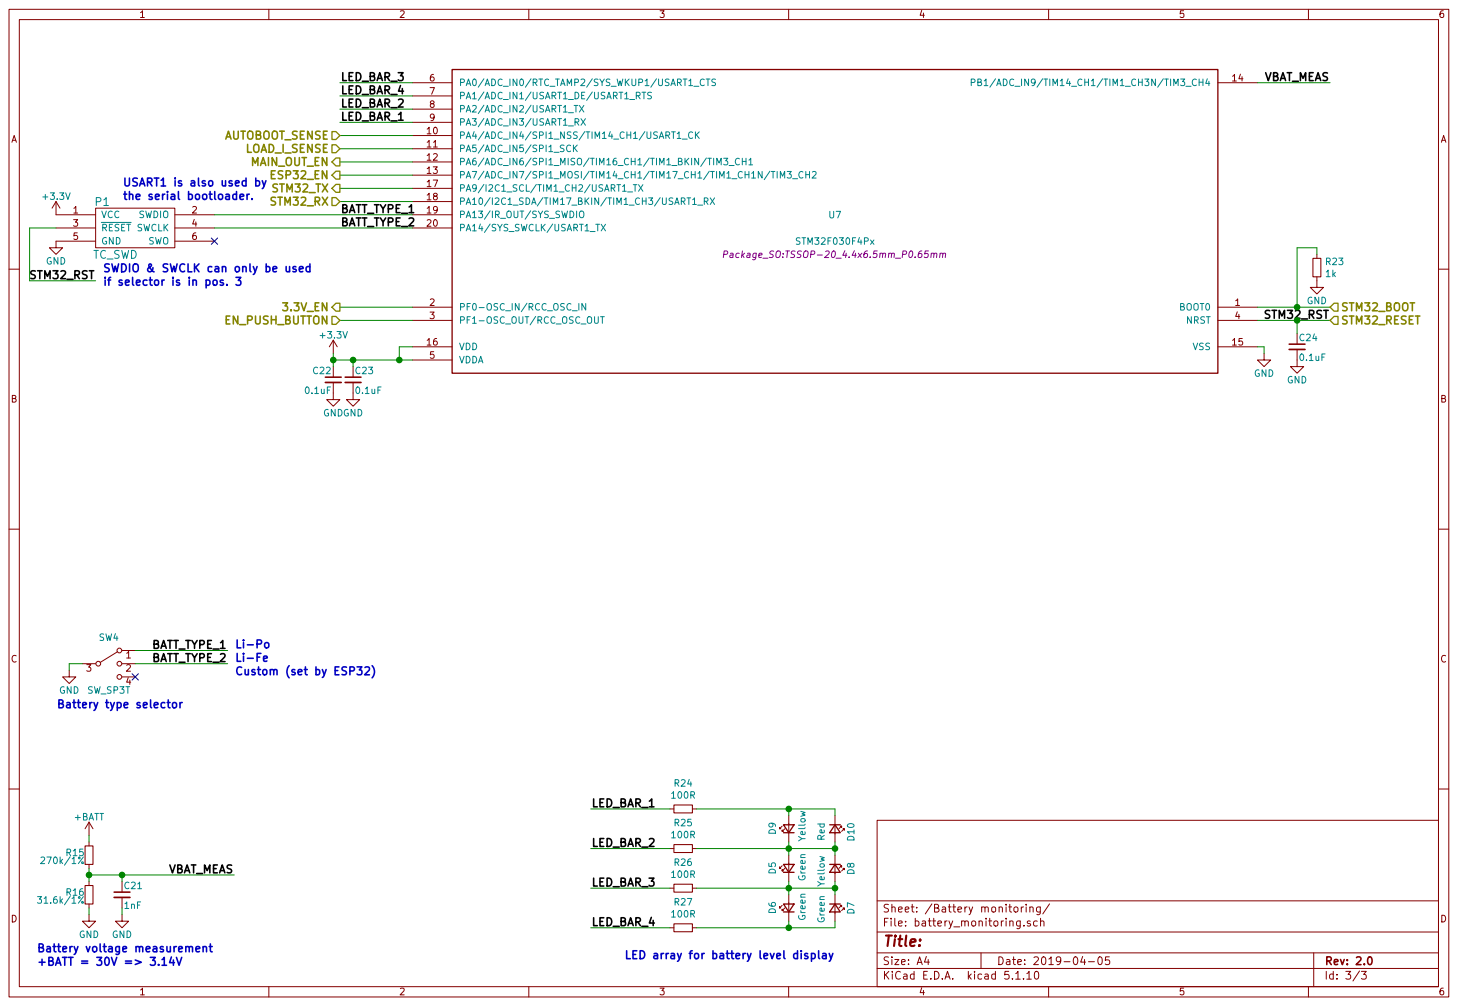
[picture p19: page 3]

USART1 is also used by
the serial bootloader.

SWDIO & SWCLK can only be used
if selector is in pos. 3

LED array for battery level display Li-Po
Li-Fe Custom (set by ESP32)

Battery voltage measurement +BATT = 30V => 3.14V

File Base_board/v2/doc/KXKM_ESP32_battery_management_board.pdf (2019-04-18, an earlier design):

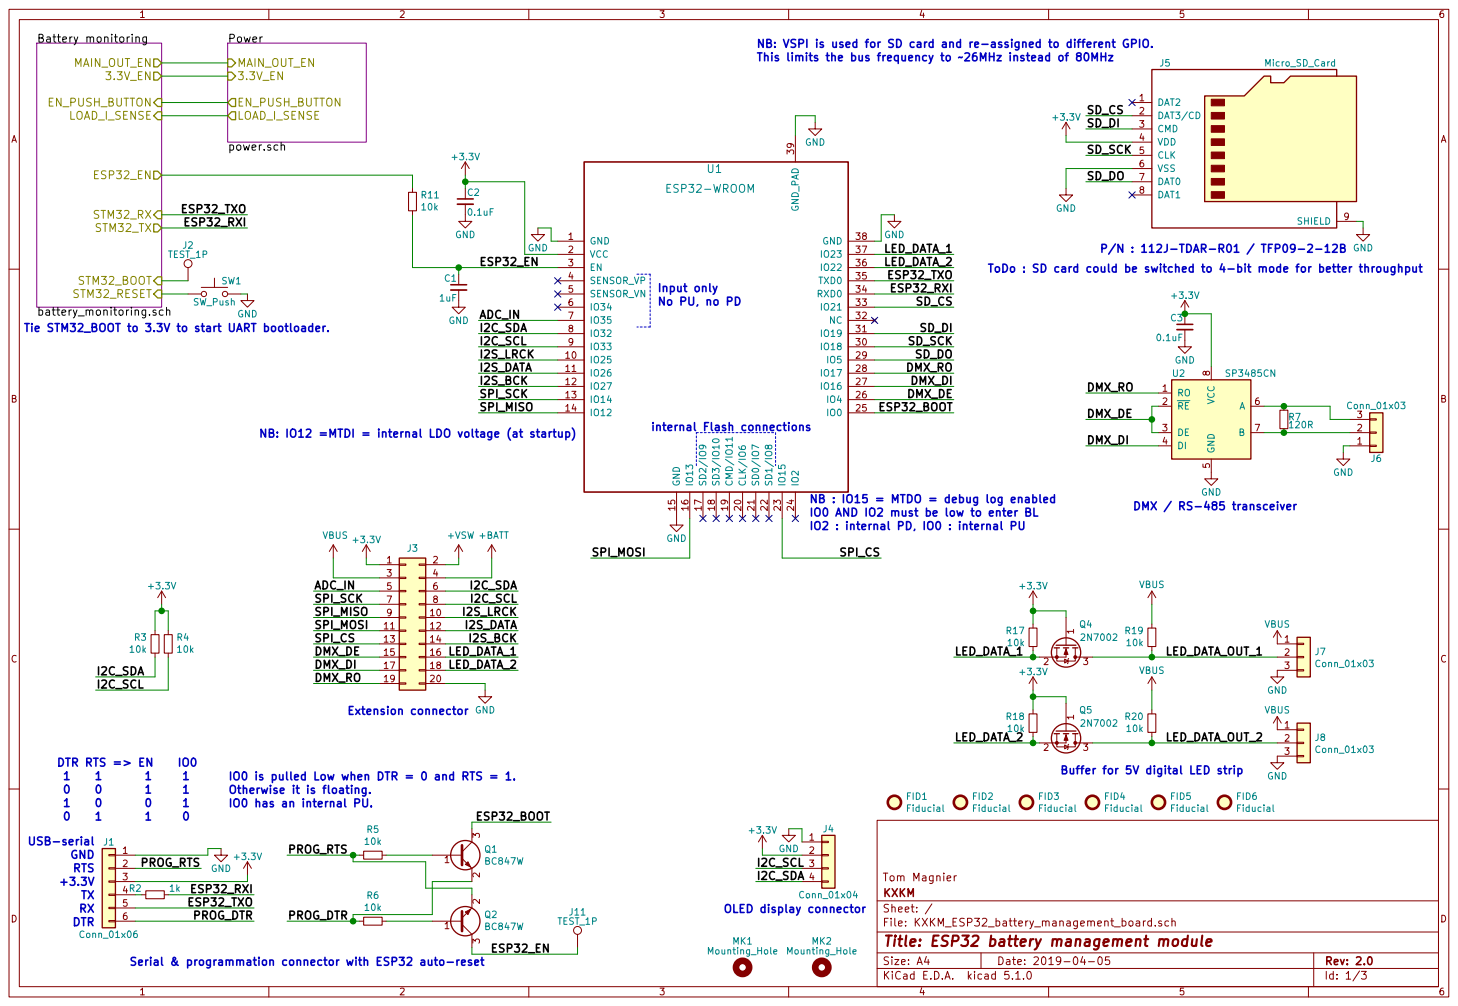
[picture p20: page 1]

NB: VSPI is used for SD card and re-assigned to different GPIO.
This limits the bus frequency to 26MHz instead of 80MHz
Tom Magnier GND_PAD 39
10k P/N : 112J-TDAR-R01 / TFP09-2-12B

Input only

I2C_SCL | IO33 9
I2S_LRCK | | IO25 10 | SD_DO
I2S_DATA | IO26 11
I2S_BCK | IO27 12

IO14 13 | DMX_DE

internal Flash connections NB: IO12 =MTDI = internal LDO voltage (at startup)

DMX / RS-485 transceiver GND

NB : IO15 = MTDO = debug log enabled
IO0 AND IO2 must be low to enter BL
IO2 : internal PD, IO0 : internal PU

IO0 is pulled Low when DTR = 0 and RTS = 1.
Otherwise it is floating.

Buffer for 5V digital LED strip

File: KXKM_ESP32_battery_management_board.sch Sheet: / KXKM

Id: 1/3 Title: ESP32 battery management module

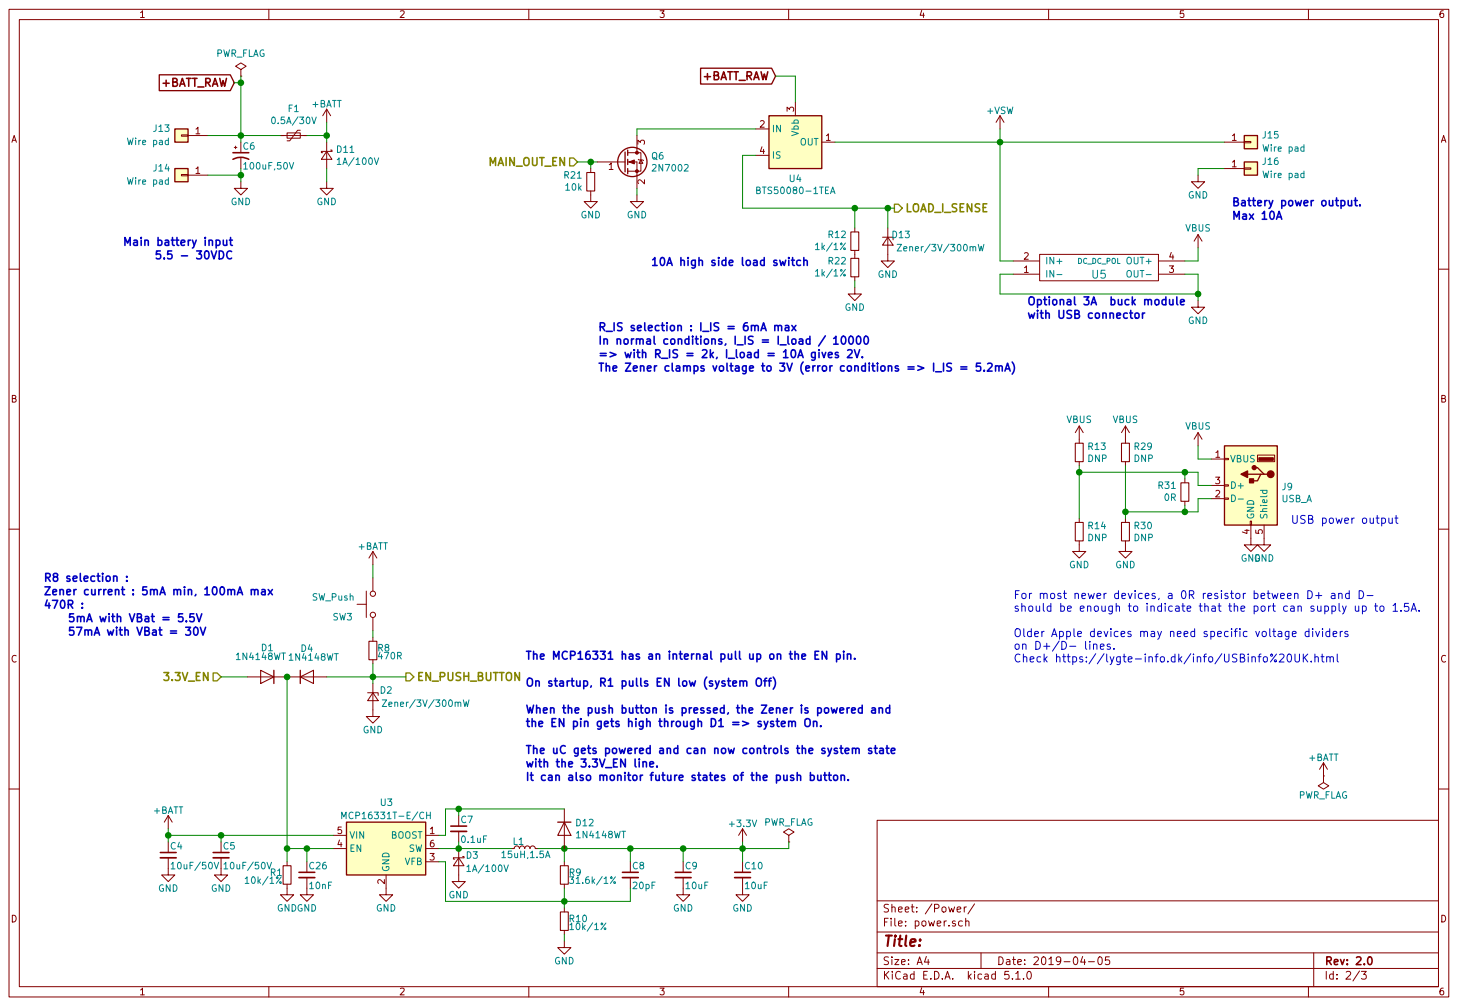
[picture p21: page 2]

Battery power output. Max 10A

The Zener clamps voltage to 3V (error conditions => I_IS = 5.2mA) D13Zener/3V/300mW

Check https://lygte-info.dk/info/USBinfo%20UK.html VBUS R29 DNP R30 DNP R14 DNP R13 DNP

PWR_FLAG R8 selection : Zener current : 5mA min, 100mA max 470R :

For most newer devices, a 0R resistor between D+ and D-
should be enough to indicate that the port can supply up to 1.5A.

Older Apple devices may need specific voltage dividers
on D+/D- lines.

The MCP16331 has an internal pull up on the EN pin.

On startup, R1 pulls EN low (system Off)

When the push button is pressed, the Zener is powered and
the EN pin gets high through D1 => system On.

The uC gets powered and can now controls the system state
with the 3.3V_EN line.
It can also monitor future states of the push button.

2 VFB 3 EN 4 VIN 5 SW 6 U3 MCP16331T-E/CH

File: power.sch Sheet: /Power/
Id: 2/3 Title:


if selector is in pos. 3 GND

SWDIO & SWCLK can only be used

Thermistor for ambient temperature measurement
Drive TEMP_MEAS low between measurements
to avoid self heating

+BATT Battery voltage measurement +BATT = 30V => 3.14V

LED array for battery level display









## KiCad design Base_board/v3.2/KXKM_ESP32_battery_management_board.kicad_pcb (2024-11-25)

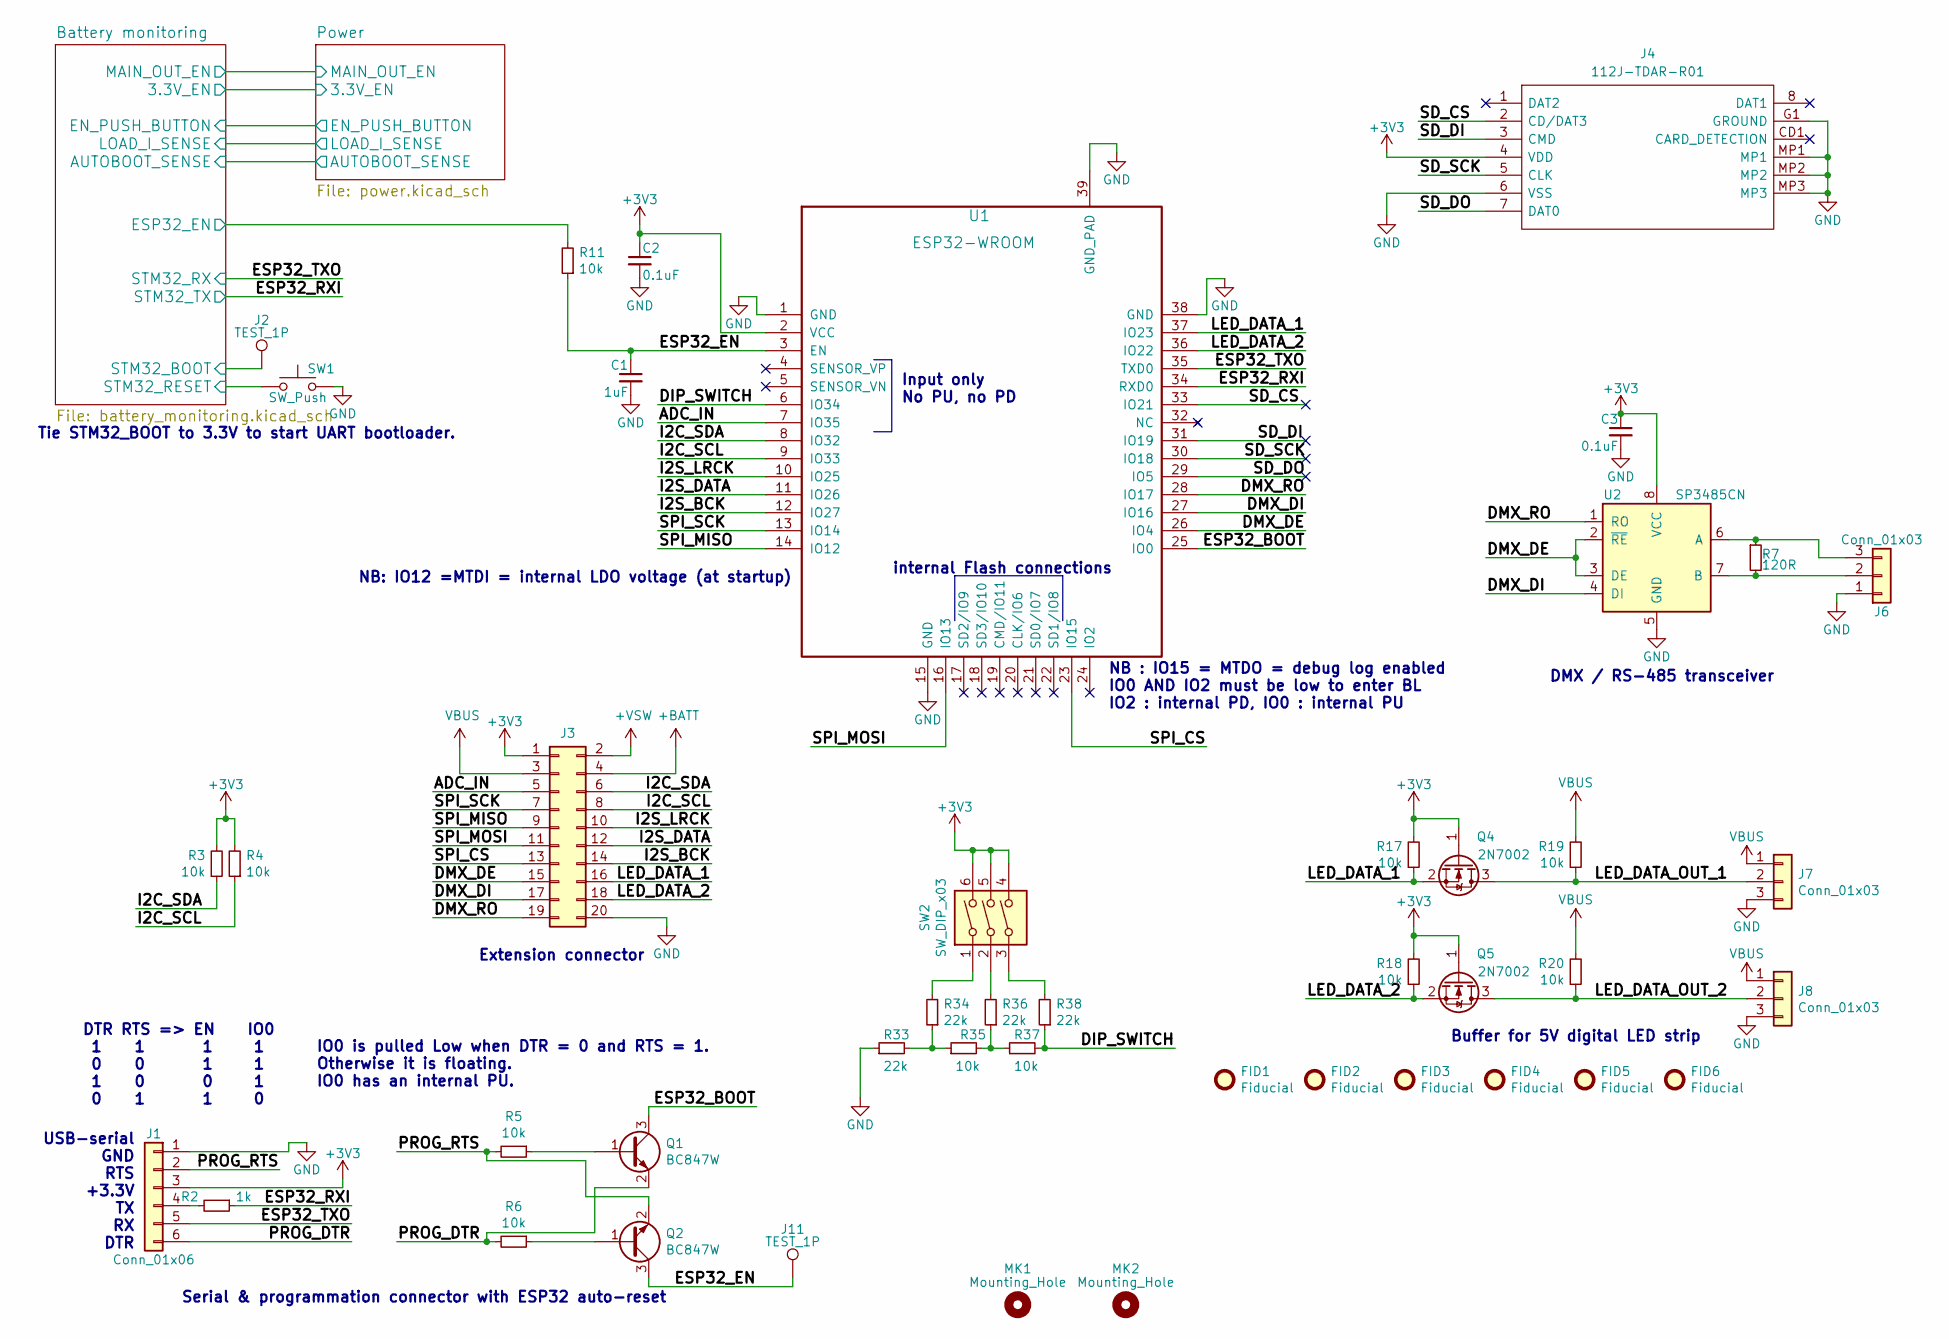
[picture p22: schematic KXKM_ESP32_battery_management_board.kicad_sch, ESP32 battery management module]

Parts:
C1: 1uF; C_0603_1608Metric; LCSC C15849
C2, C3: 0.1uF; C_0603_1608Metric; LCSC C14663
FID1, FID2, FID3, FID4, FID5, FID6: Fiducial; Fiducial_0.5mm_Mask1mm
J1: Conn_01x06; PinHeader_1x06_P2.54mm_Vertical
J2, J11: TEST_1P; TestPoint_Pad_D1.5mm
J3: Conn_02x10_Odd_Even; PinSocket_2x10_P2.54mm_Vertical_SMD
J4: 112J-TDAR-R01; 112JTDARR01; Manufacturer_Part_Number 112J-TDAR-R01
J6: Conn_01x03; PinHeader_1x03_P2.54mm_Vertical
J7, J8: Conn_01x03; JST_EH_B3B-EH-A_1x03_P2.50mm_Vertical
MK1, MK2: Mounting_Hole; MountingHole_3.2mm_M3
Q1, Q2: BC847W; SOT-323_SC-70; LCSC C130418
Q4, Q5: 2N7002; SOT-23; LCSC C8545
R2: 1k; R_0603_1608Metric; LCSC C21190
R3, R4, R5, R6, R11, R17, R18, R19, R20, R35, R37: 10k; R_0603_1608Metric; LCSC C25804
R7: 120R; R_0603_1608Metric; LCSC C114681
R33, R34, R36, R38: 22k; R_0603_1608Metric; LCSC C31850
SW1: SW_Push; SW_SPST_KMR2; LCSC C128941
SW2: SW_DIP_x03; SW_DIP_SPSTx03_Piano_CTS_Series194-3MSTN_W7.62mm_P2.54mm; LCSC C319070
U1: ESP32-WROOM; ESP32-WROOM-32U; LCSC C529580
U2: SP3485CN; SOIC-8_3.9x4.9mm_P1.27mm; LCSC C668205

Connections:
+3V3: C2.1, C3.1, J1.3, J3.1, J4.4 (VDD), Q4.1 (G), Q5.1 (G), R3.2, R4.2, R17.2, R18.2, SW2.4, SW2.5, SW2.6, U1.2 (VCC), U2.8 (VCC); also elsewhere on the board
+BATT: J3.4; also elsewhere on the board
+VSW: J3.2; also elsewhere on the board
/ADC_IN: J3.5, U1.7 (IO35)
/Battery monitoring/ESP32_EN: R11.2; also elsewhere on the board
/Battery monitoring/STM32_BOOT: J2.1; also elsewhere on the board
/Battery monitoring/STM32_RST: SW1.1; also elsewhere on the board
/DIP_SWITCH: R37.2, R38.1, U1.6 (IO34)
/DMX_DE: J3.15, U1.26 (IO4), U2.2 (~RE), U2.3 (DE)
/DMX_DI: J3.17, U1.27 (IO16), U2.4 (DI)
/DMX_RO: J3.19, U1.28 (IO17), U2.1 (RO)
/ESP32_BOOT: Q1.3 (C), U1.25 (IO0)
/ESP32_EN: C1.1, J11.1, Q2.3 (C), R11.1, U1.3 (EN)
/ESP32_RXI: R2.1, U1.34 (RXD0); also elsewhere on the board
/ESP32_TXO: J1.5, U1.35 (TXD0); also elsewhere on the board
/I2C_SCL: J3.8, R4.1, U1.9 (IO33)
/I2C_SDA: J3.6, R3.1, U1.8 (IO32)
/I2S_BCK: J3.14, U1.12 (IO27)
/I2S_DATA: J3.12, U1.11 (IO26)
/I2S_LRCK: J3.10, U1.10 (IO25)
/LED_DATA_1: J3.16, Q4.2 (S), R17.1, U1.37 (IO23)
/LED_DATA_2: J3.18, Q5.2 (S), R18.1, U1.36 (IO22)
/LED_DATA_OUT_1: J7.2, Q4.3 (D), R19.1
/LED_DATA_OUT_2: J8.2, Q5.3 (D), R20.1
/PROG_DTR: J1.6, Q1.2 (E), R6.2
/PROG_RTS: J1.2, Q2.2 (E), R5.2
/SD_CS: J4.2 (CD/DAT3), U1.33 (IO21)
/SD_DI: J4.3 (CMD), U1.31 (IO19)
/SD_DO: J4.7 (DAT0), U1.29 (IO5)
/SD_SCK: J4.5 (CLK), U1.30 (IO18)
/SPI_CS: J3.13, U1.23 (IO15)
/SPI_MISO: J3.9, U1.14 (IO12)
/SPI_MOSI: J3.11, U1.16 (IO13)
/SPI_SCK: J3.7, U1.13 (IO14)
GND: C1.2, C2.2, C3.2, J1.1, J3.20, J4.6 (VSS), J4.G1 (GROUND), J4.MP1, J4.MP2, J4.MP3, J6.1, J7.3, J8.3, R33.1, SW1.2, U1.1 (GND), U1.15 (GND), U1.38 (GND), U1.39 (GND_PAD), U2.5 (GND); also elsewhere on the board
unnamed: J1.4, R2.2
unnamed: J6.2, R7.2, U2.7 (B)
unnamed: J6.3, R7.1, U2.6 (A)
unnamed: Q1.1 (B), R5.1
unnamed: Q2.1 (B), R6.1
unnamed: R33.2, R34.1, R35.1
unnamed: R34.2, SW2.1
unnamed: R35.2, R36.1, R37.1
unnamed: R36.2, SW2.2
unnamed: R38.2, SW2.3
VBUS: J3.3, J7.1, J8.1, R19.2, R20.2; also elsewhere on the board

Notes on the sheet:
DMX / RS-485 transceiver
Tie STM32_BOOT to 3.3V to start UART bootloader.
DTR RTS => EN IO0 1 1 1 1 0 0 1 1 1 0 0 1 0 1 1 0
Input only No PU, no PD
Buffer for 5V digital LED strip
USB-serial GND RTS +3.3V TX RX DTR
NB : IO15 = MTDO = debug log enabled IO0 AND IO2 must be low to enter BL IO2 : internal PD, IO0 : internal PU
Serial & programmation connector with ESP32 auto-reset
IO0 is pulled Low when DTR = 0 and RTS = 1. Otherwise it is floating. IO0 has an internal PU.
NB: IO12 =MTDI = internal LDO voltage (at startup)
internal Flash connections
Extension connector

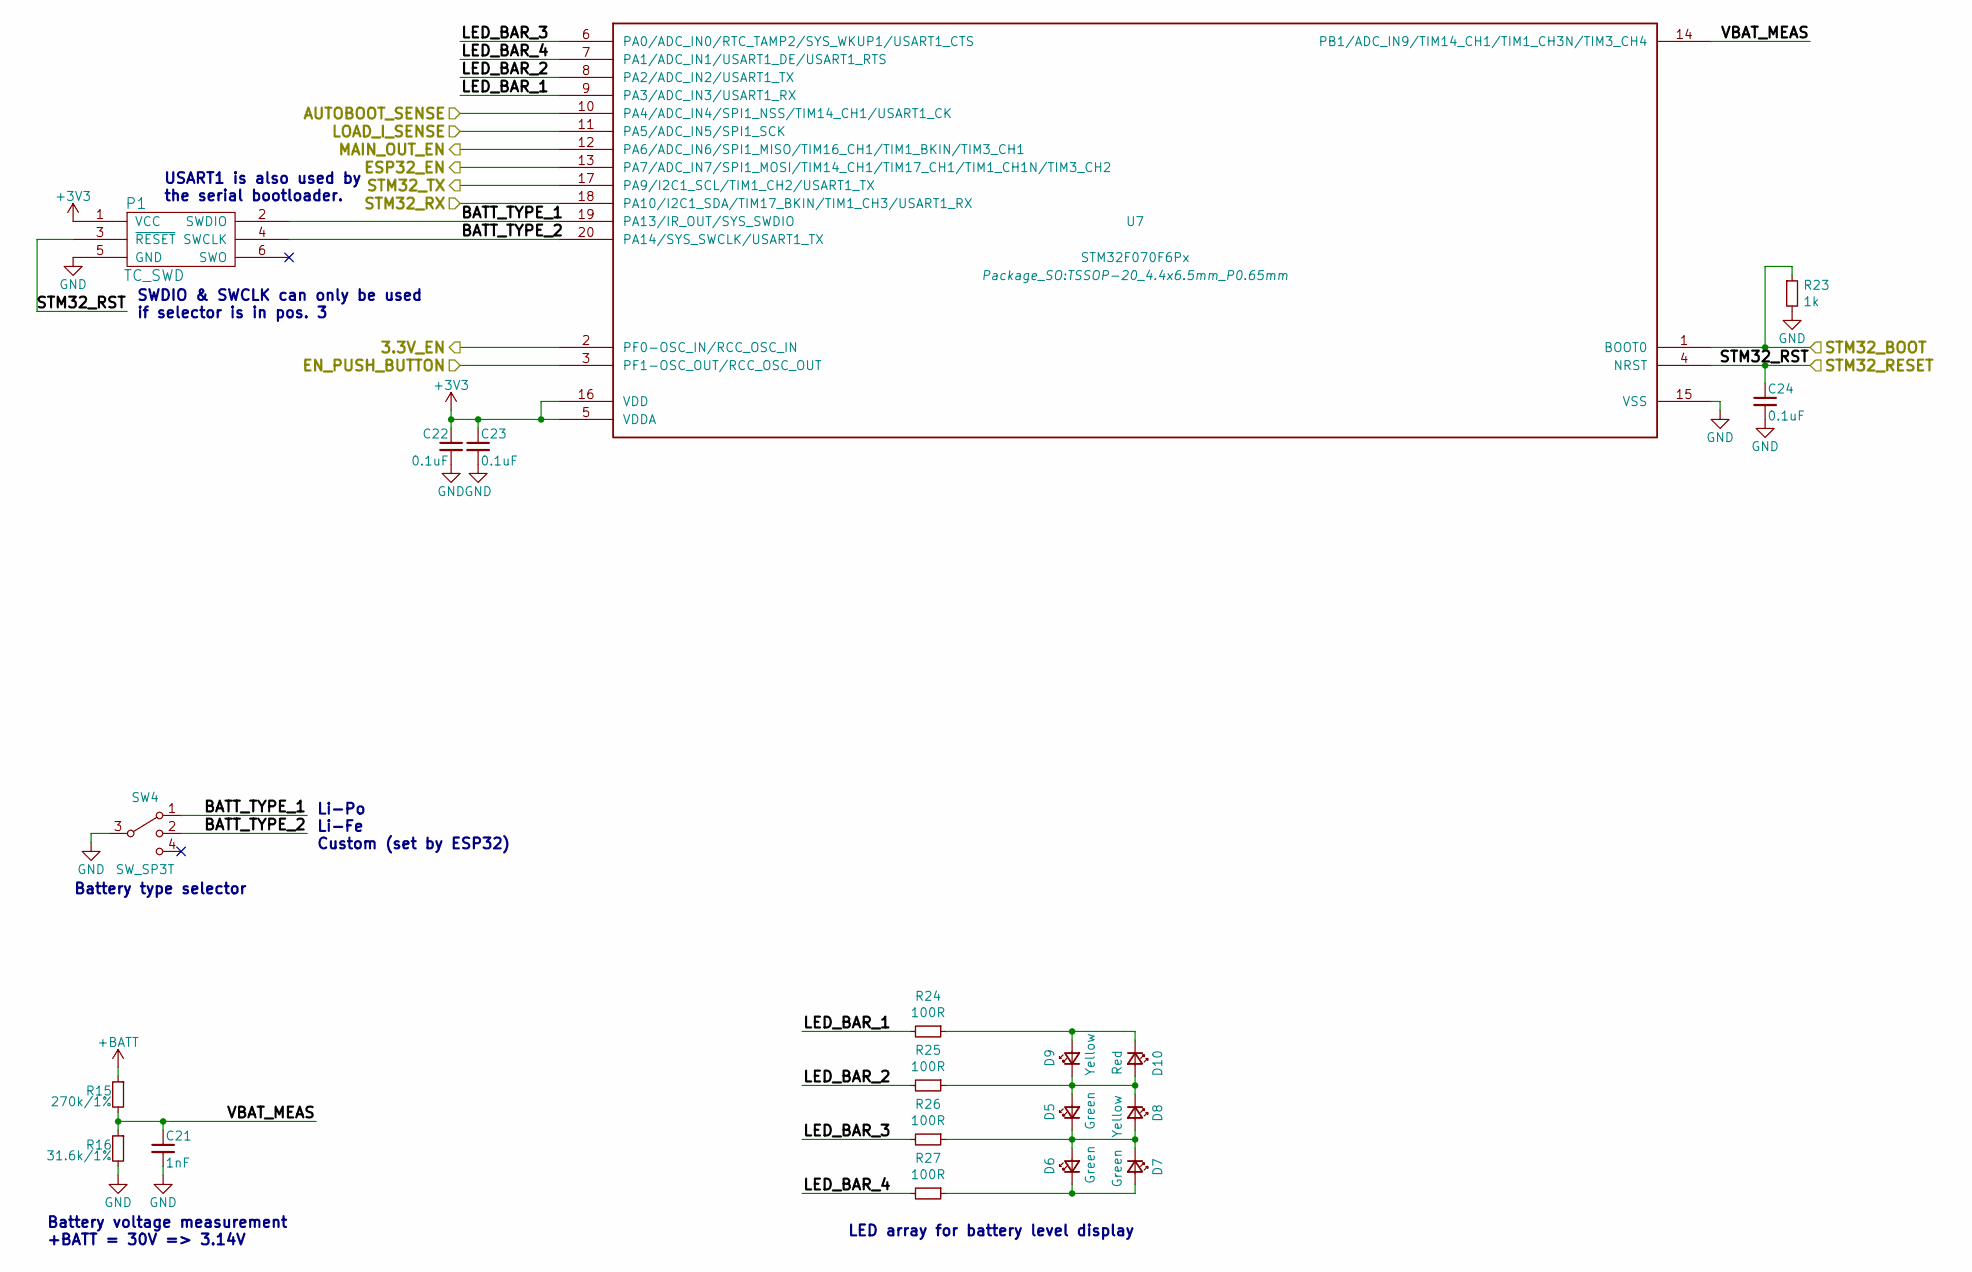
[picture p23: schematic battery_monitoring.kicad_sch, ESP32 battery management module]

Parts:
C21: 1nF; C_0603_1608Metric
C22, C23, C24: 0.1uF; C_0603_1608Metric; LCSC C14663
D5, D6, D7: Green; LED_0603_1608Metric; LCSC C72043
D8, D9: Yellow; LED_0603_1608Metric; LCSC C72038
D10: Red; LED_0603_1608Metric; LCSC C2286
P1: TC_SWD; Tag-Connect_TC2030-IDC-NL_2x03_P1.27mm_Vertical
R15: 270k/1%; R_0603_1608Metric; LCSC C22965
R16: 31.6k/1%; R_0603_1608Metric; LCSC C25967
R23: 1k; R_0603_1608Metric; LCSC C21190
R24, R25, R26, R27: 100R; R_0603_1608Metric; LCSC C22775
SW4: SW_SP3T; SW_SP3T_PCM13; LCSC C160878
U7: STM32F070F6Px; TSSOP-20_4.4x6.5mm_P0.65mm; LCSC C86951

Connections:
+3V3: C22.1, C23.1, P1.1 (VCC), U7.5 (VDDA), U7.16 (VDD); also elsewhere on the board
+BATT: R15.1; also elsewhere on the board
/Battery monitoring/3.3V_EN: U7.2 (PF0-OSC_IN/RCC_OSC_IN); also elsewhere on the board
/Battery monitoring/AUTOBOOT_SENSE: U7.10 (PA4/ADC_IN4/SPI1_NSS/TIM14_CH1/USART1_CK); also elsewhere on the board
/Battery monitoring/BATT_TYPE_1: P1.2 (SWDIO), SW4.1, U7.19 (PA13/IR_OUT/SYS_SWDIO)
/Battery monitoring/BATT_TYPE_2: P1.4 (SWCLK), SW4.2, U7.20 (PA14/SYS_SWCLK/USART1_TX)
/Battery monitoring/EN_PUSH_BUTTON: U7.3 (PF1-OSC_OUT/RCC_OSC_OUT); also elsewhere on the board
/Battery monitoring/ESP32_EN: U7.13 (PA7/ADC_IN7/SPI1_MOSI/TIM14_CH1/TIM17_C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); also elsewhere on the board
/Battery monitoring/LED_BAR_1: R24.2, U7.9 (PA3/ADC_IN3/USART1_RX)
/Battery monitoring/LED_BAR_2: R25.2, U7.8 (PA2/ADC_IN2/USART1_TX)
/Battery monitoring/LED_BAR_3: R26.2, U7.6 (PA0/ADC_IN0/RTC_TAMP2/SYS_WKUP1/USART1_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)
/Battery monitoring/LED_BAR_4: R27.2, U7.7 (PA1/ADC_IN1/USART1_DE/USART1_RTS)
/Battery monitoring/LOAD_I_SENSE: U7.11 (PA5/ADC_IN5/SPI1_SCK); also elsewhere on the board
/Battery monitoring/MAIN_OUT_EN: U7.12 (PA6/ADC_IN6/SPI1_MISO/TIM16_CH1/TIM1_BK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); also elsewhere on the board
/Battery monitoring/STM32_BOOT: R23.1, U7.1 (BOOT0); also elsewhere on the board
/Battery monitoring/STM32_RST: C24.1, P1.3 (~RESET), U7.4 (NRST); also elsewhere on the board
/Battery monitoring/VBAT_MEAS: C21.1, R15.2, R16.1, U7.14 (PB1/ADC_IN9/TIM14_CH1/TIM1_CH3N/TIM3_CH4)
/ESP32_RXI: U7.17 (PA9/I2C1_SCL/TIM1_CH2/USART1_TX); also elsewhere on the board
/ESP32_TXO: U7.18 (PA10/I2C1_SDA/TIM17_BKIN/TIM1_CH3/USART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); also elsewhere on the board
GND: C21.2, C22.2, C23.2, C24.2, P1.5 (GND), R16.2, R23.2, SW4.3, U7.15 (VSS); also elsewhere on the board
unnamed: D5.1 (K), D6.2 (A), D7.1 (K), D8.2 (A), R26.1
unnamed: D6.1 (K), D7.2 (A), R27.1
unnamed: D5.2 (A), D8.1 (K), D9.1 (K), D10.2 (A), R25.1
unnamed: D9.2 (A), D10.1 (K), R24.1

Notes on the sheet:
Li-Po Li-Fe Custom (set by ESP32)
Battery type selector
Battery voltage measurement +BATT = 30V => 3.14V
LED array for battery level display
SWDIO & SWCLK can only be used if selector is in pos. 3
USART1 is also used by the serial bootloader.

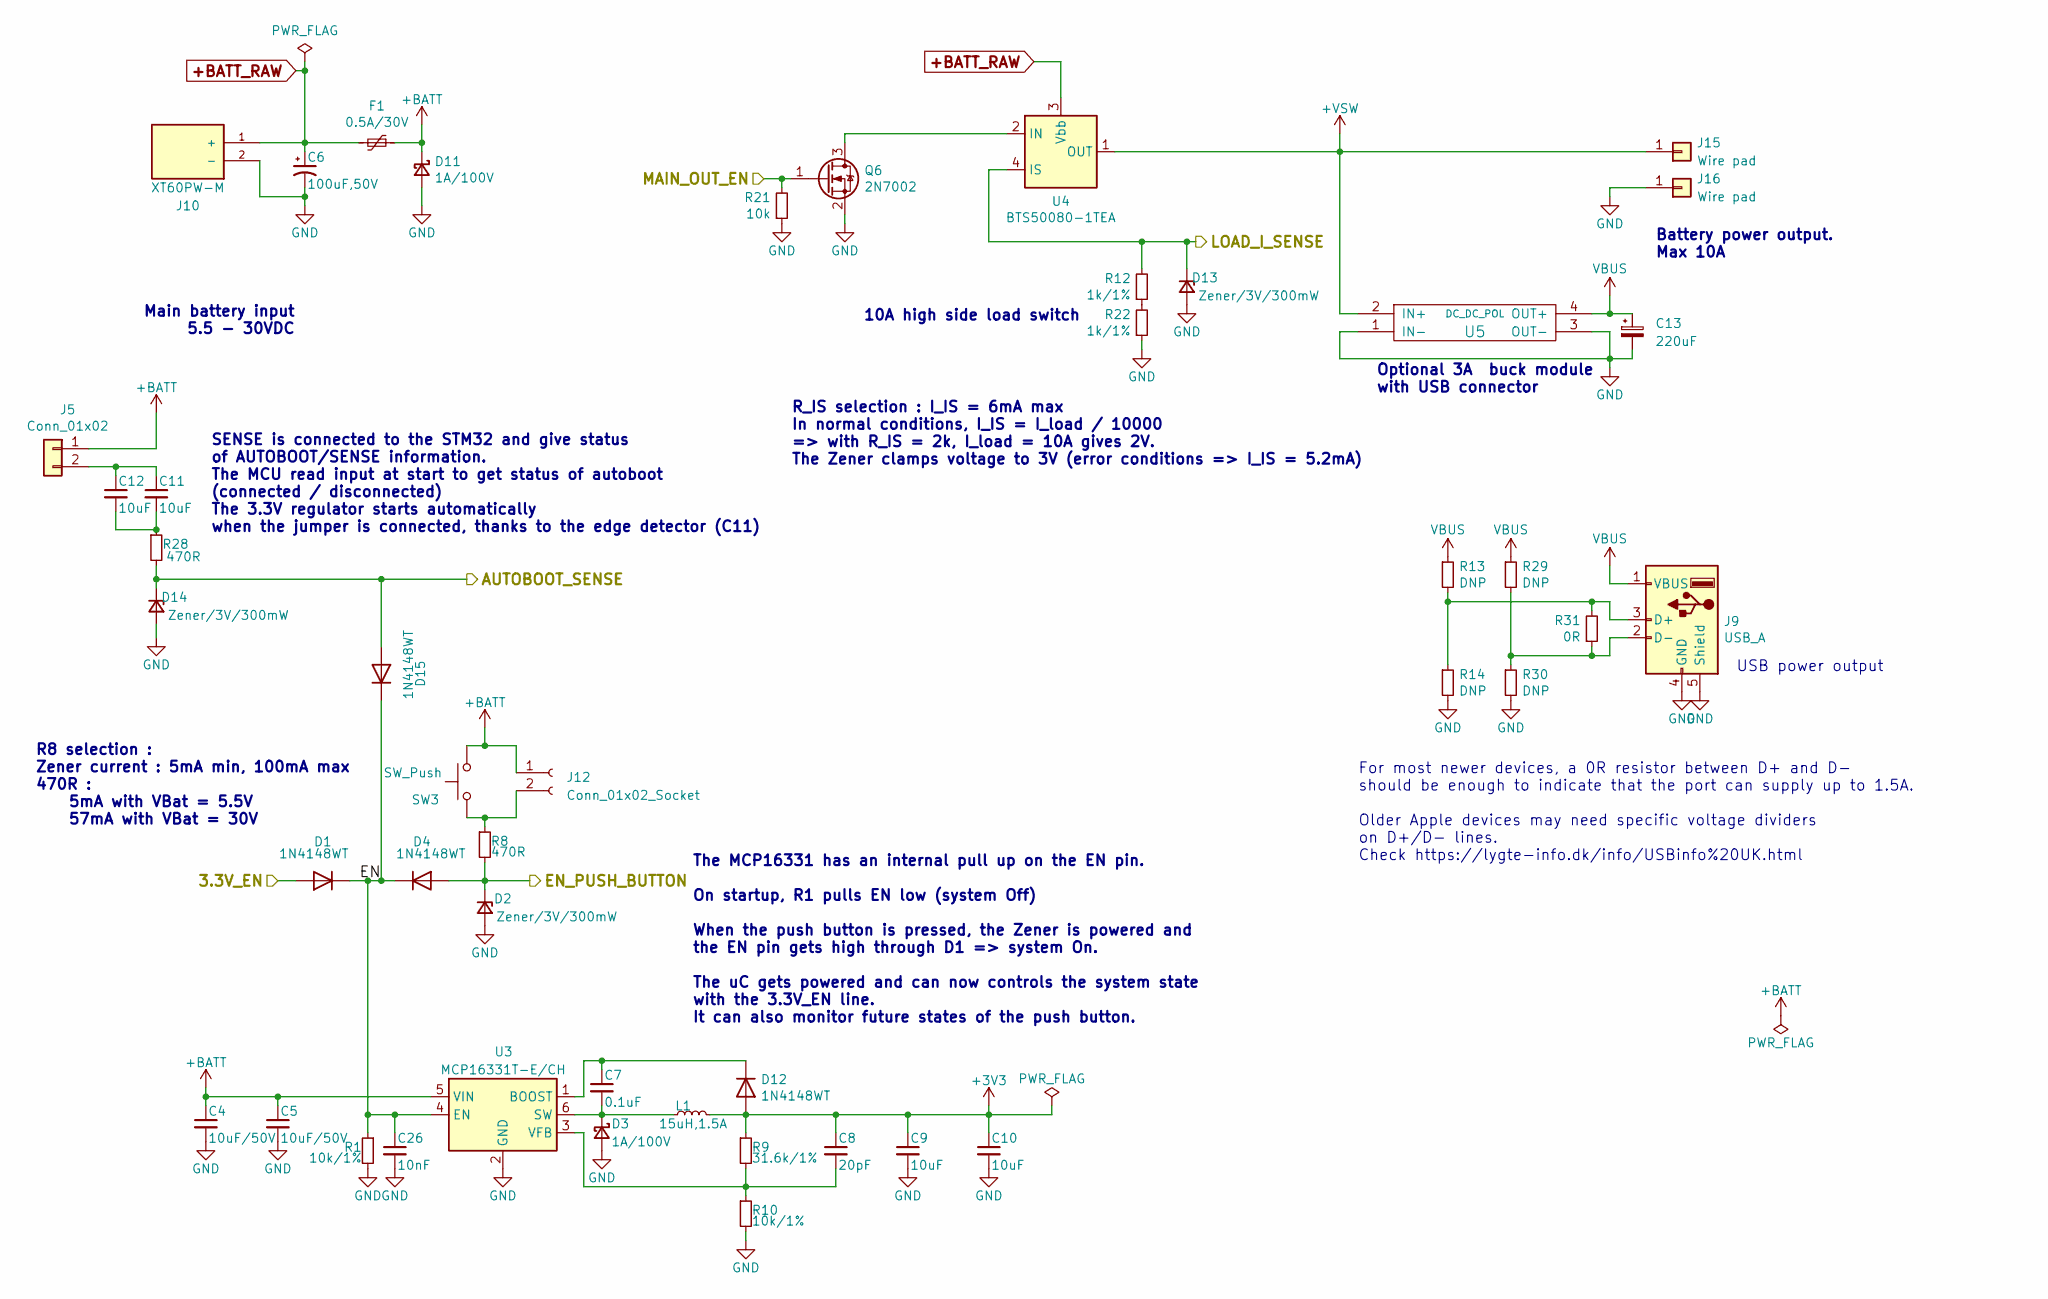
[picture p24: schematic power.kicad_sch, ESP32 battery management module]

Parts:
C4, C5: 10uF/50V; C_1206_3216Metric; LCSC C13585
C6: 100uF,50V; CP_Elec_8x10; LCSC C97812
C7: 0.1uF; C_0603_1608Metric; LCSC C14663
C8: 20pF; C_0603_1608Metric; LCSC C1648
C9, C10, C11, C12: 10uF; C_0805_2012Metric
C13: 220uF; CP_Radial_D5.0mm_P2.50mm
C26: 10nF; C_0603_1608Metric; LCSC C57112
D1, D4, D12, D15: 1N4148WT; D_SOD-523; LCSC C68948
D2, D13, D14: Zener/3V/300mW; D_SOD-323; LCSC C19869
D3, D11: 1A/100V; D_SMA; LCSC C14996
F1: 0.5A/30V; Fuse_1812_4532Metric; LCSC C2924945
J5: Conn_01x02; PinHeader_1x02_P2.54mm_Vertical
J9: USB_A; USB_A_Female; LCSC C2345
J10: XT60PW-M; AMASS_XT60PW-M; Manufacturer_Part_Number XT60PW-M
J12: Conn_01x02_Socket; PinHeader_1x02_P2.54mm_Vertical
J15, J16: Wire pad; SolderWirePad_1x01_Drill2mm
L1: 15uH,1.5A; L_Taiyo-Yuden_NR-50xx; LCSC C206232
Q6: 2N7002; SOT-23; LCSC C8545
R1, R10: 10k/1%; R_0603_1608Metric; LCSC C25804
R8, R28: 470R; R_0603_1608Metric; LCSC C23179
R9: 31.6k/1%; R_0603_1608Metric; LCSC C25967
R12, R22: 1k/1%; R_0603_1608Metric; LCSC C21190
R13, R14, R29, R30: DNP; R_0603_1608Metric
R21: 10k; R_0603_1608Metric; LCSC C25804
R31: 0R; R_0603_1608Metric; LCSC C21189
SW3: SW_Push; SW_Tactile_SPST_Angled_PTS645Vx31-2LFS; LCSC C127680
U3: MCP16331T-E/CH; SOT-23-6; LCSC C105695
U4: BTS50080-1TEA; TO-252-4; LCSC C152393
U5: DC_DC_POL; DC_DC_Buck_module_22x17mm

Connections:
+3V3: C8.1, C9.1, C10.1, D12.2 (A), L1.2, R9.1; also elsewhere on the board
+BATT: C4.1, C5.1, D11.1 (K), F1.1, J5.1, J12.1, SW3.2, U3.5 (VIN); also elsewhere on the board
+BATT_RAW: C6.1, F1.2, J10.1 (+), U4.3 (Vbb)
+VSW: J15.1, U4.1 (OUT), U4.5 (OUT), U5.2 (IN+); also elsewhere on the board
/Battery monitoring/3.3V_EN: D1.2 (A); also elsewhere on the board
/Battery monitoring/AUTOBOOT_SENSE: D14.1 (K), D15.2 (A), R28.2; also elsewhere on the board
/Battery monitoring/EN_PUSH_BUTTON: D2.1 (K), D4.2 (A), R8.2; also elsewhere on the board
/Battery monitoring/LOAD_I_SENSE: D13.1 (K), R12.2, U4.4 (IS); also elsewhere on the board
/Battery monitoring/MAIN_OUT_EN: Q6.1 (G), R21.2; also elsewhere on the board
/Power/EN: C26.1, D1.1 (K), D4.1 (K), D15.1 (K), R1.1, U3.4 (EN)
GND: C4.2, C5.2, C6.2, C9.2, C10.2, C13.2, C26.2, D2.2 (A), D3.2 (A), D11.2 (A), D13.2 (A), D14.2 (A), J9.4 (GND), J9.5 (Shield), J10.2 (-), J16.1, Q6.2 (S), R1.2, R10.2, R14.2, R21.1, R22.1, R30.2, SW3.3, SW3.4, U3.2 (GND), U5.1 (IN-), U5.3 (OUT-); also elsewhere on the board
unnamed: C11.2, C12.2, R28.1
unnamed: C7.2, D3.1 (K), L1.1, U3.6 (SW)
unnamed: C7.1, D12.1 (K), U3.1 (BOOST)
unnamed: C11.1, C12.1, J5.2
unnamed: J9.3 (D+), R13.2, R14.1, R31.2
unnamed: J9.2 (D-), R29.2, R30.1, R31.1
unnamed: J12.2, R8.1, SW3.1
unnamed: Q6.3 (D), U4.2 (IN)
unnamed: R12.1, R22.2
unnamed: C8.2, R9.2, R10.1, U3.3 (VFB)
VBUS: C13.1, J9.1 (VBUS), R13.1, R29.1, U5.4 (OUT+); also elsewhere on the board

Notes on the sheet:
R8 selection : Zener current : 5mA min, 100mA max 470R : 5mA with VBat = 5.5V 57mA with VBat = 30V
For most newer devices, a 0R resistor between D+ and D- should be enough to indicate that the port can supply up to 1.5A. Older Apple devices may need specific voltage dividers on D+/D- lines. Check https://lygte-info.dk/info/USBinfo%20UK.html
R_IS selection : I_IS = 6mA max In normal conditions, I_IS = I_load / 10000 => with R_IS = 2k, I_load = 10A gives 2V. The Zener clamps voltage to 3V (error conditions => I_IS = 5.2mA)
The MCP16331 has an internal pull up on the EN pin. On startup, R1 pulls EN low (system Off) When the push button is pressed, the Zener is powered and the EN pin gets high through D1 => system On. The uC gets powered and can now controls the system state with the 3.3V_EN line. It can also monitor f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
10A high side load switch
USB power output
SENSE is connected to the STM32 and give status of AUTOBOOT/SENSE information. The MCU read input at start to get status of autoboot (connected / disconnected) The 3.3V regulator starts automatically when the jumper is connected, thanks to the edge detector (C11)
Optional 3A buck module with USB connector
Main battery input 5.5 - 30VDC
Battery power output. Max 10A

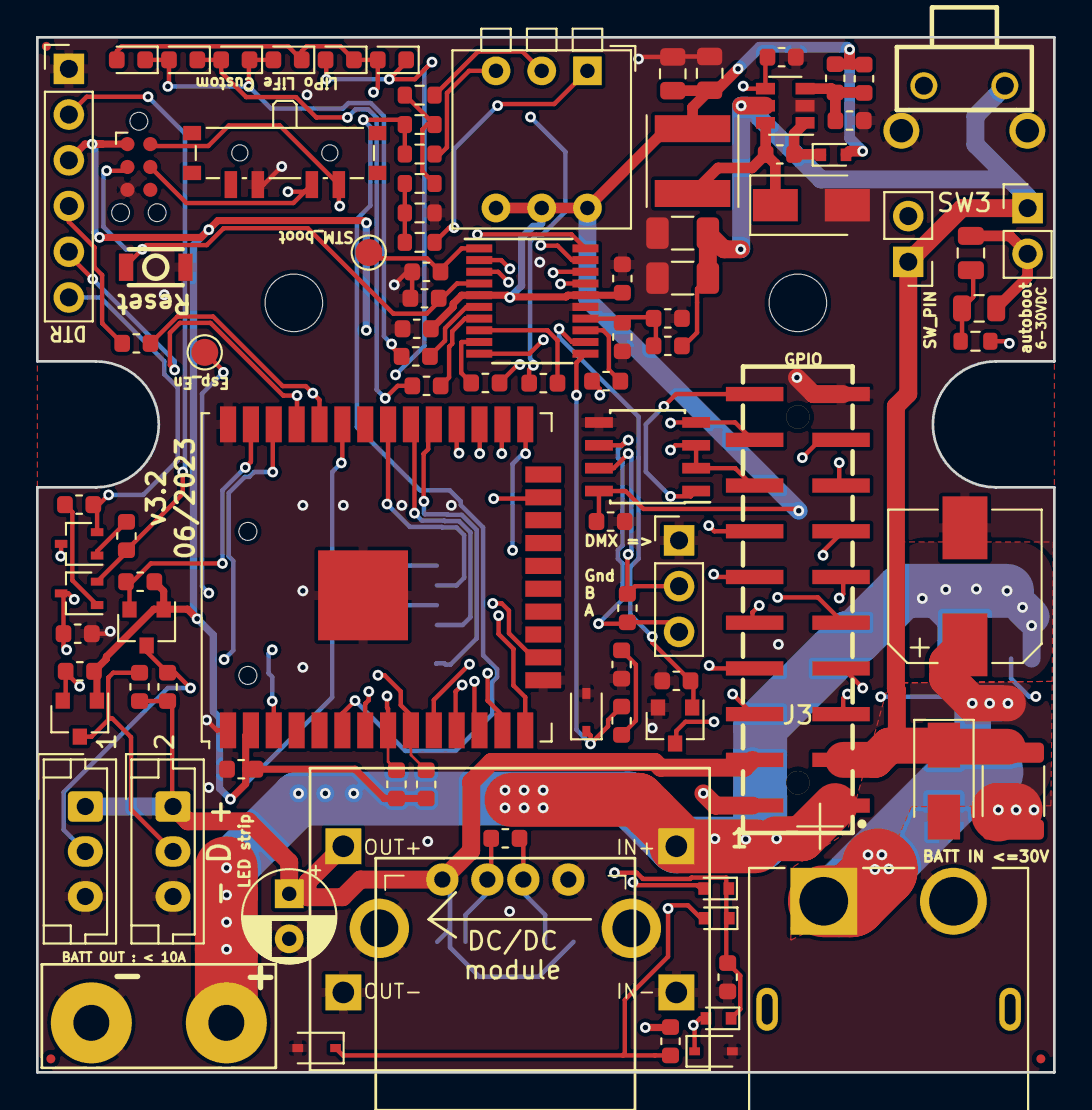
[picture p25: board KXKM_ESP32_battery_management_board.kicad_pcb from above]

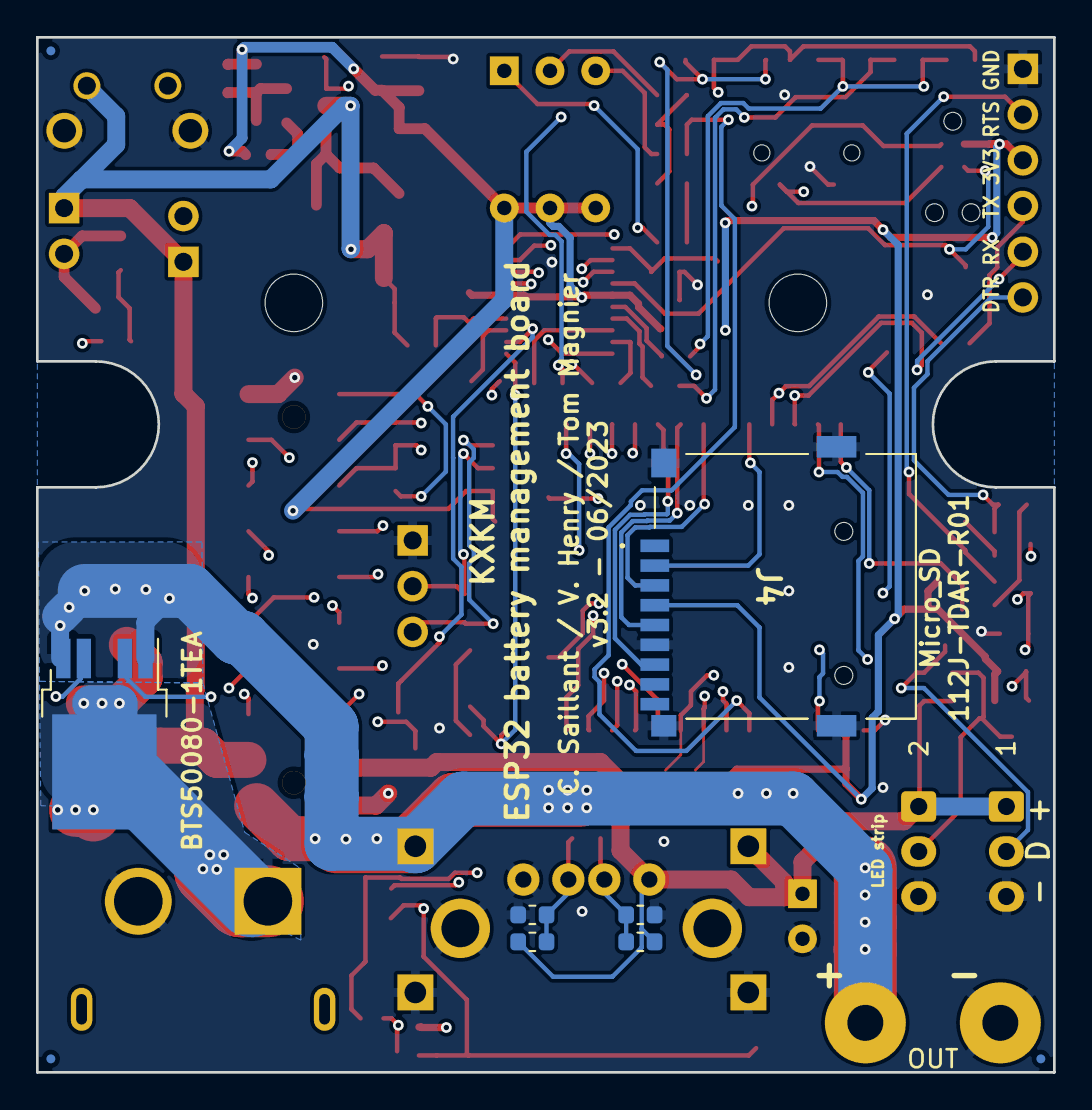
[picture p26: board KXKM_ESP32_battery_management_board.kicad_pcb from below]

Board: 4 copper layers, 56.5 x 57.5 mm, 110 parts (9 on the bottom side), 74 nets.

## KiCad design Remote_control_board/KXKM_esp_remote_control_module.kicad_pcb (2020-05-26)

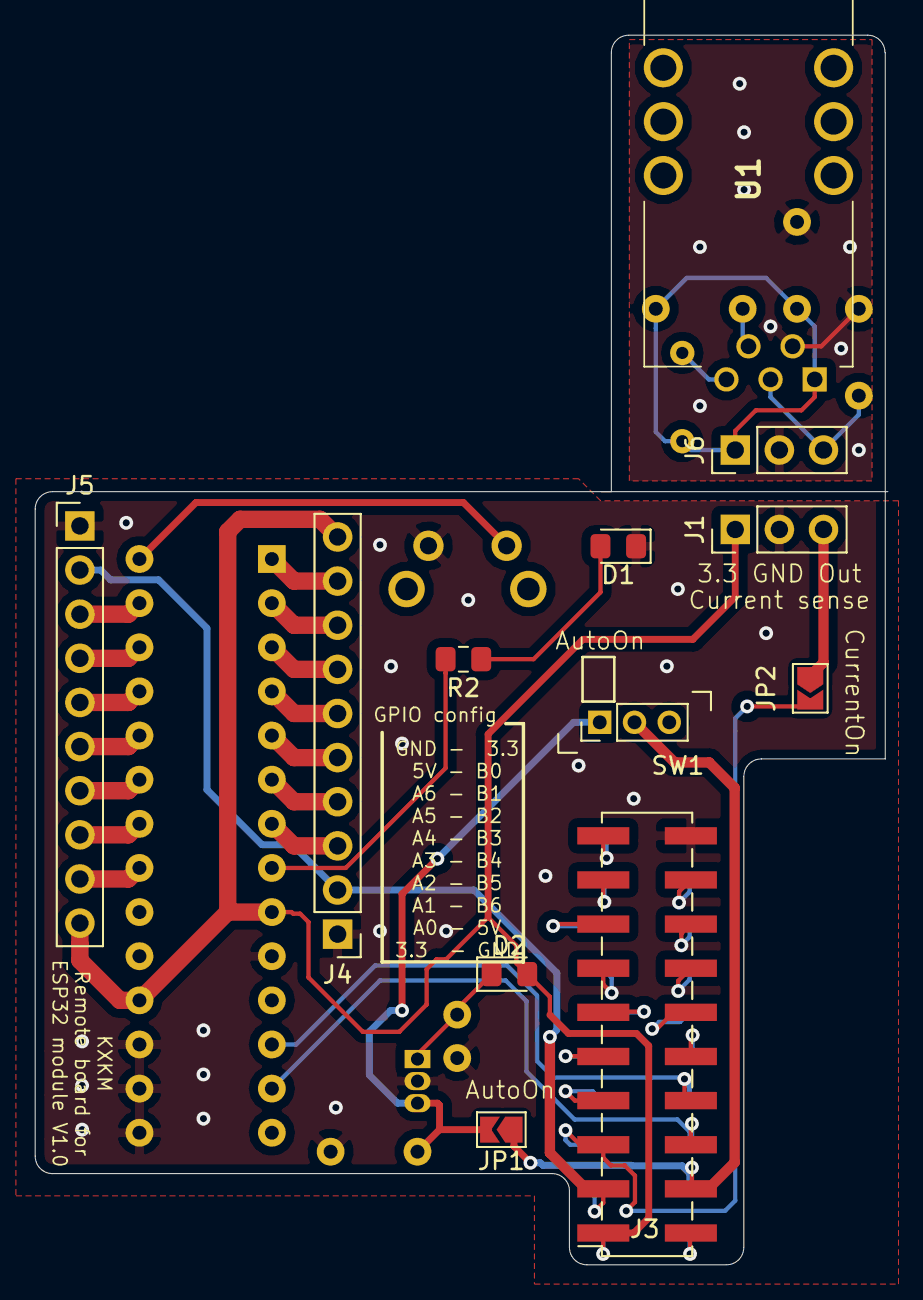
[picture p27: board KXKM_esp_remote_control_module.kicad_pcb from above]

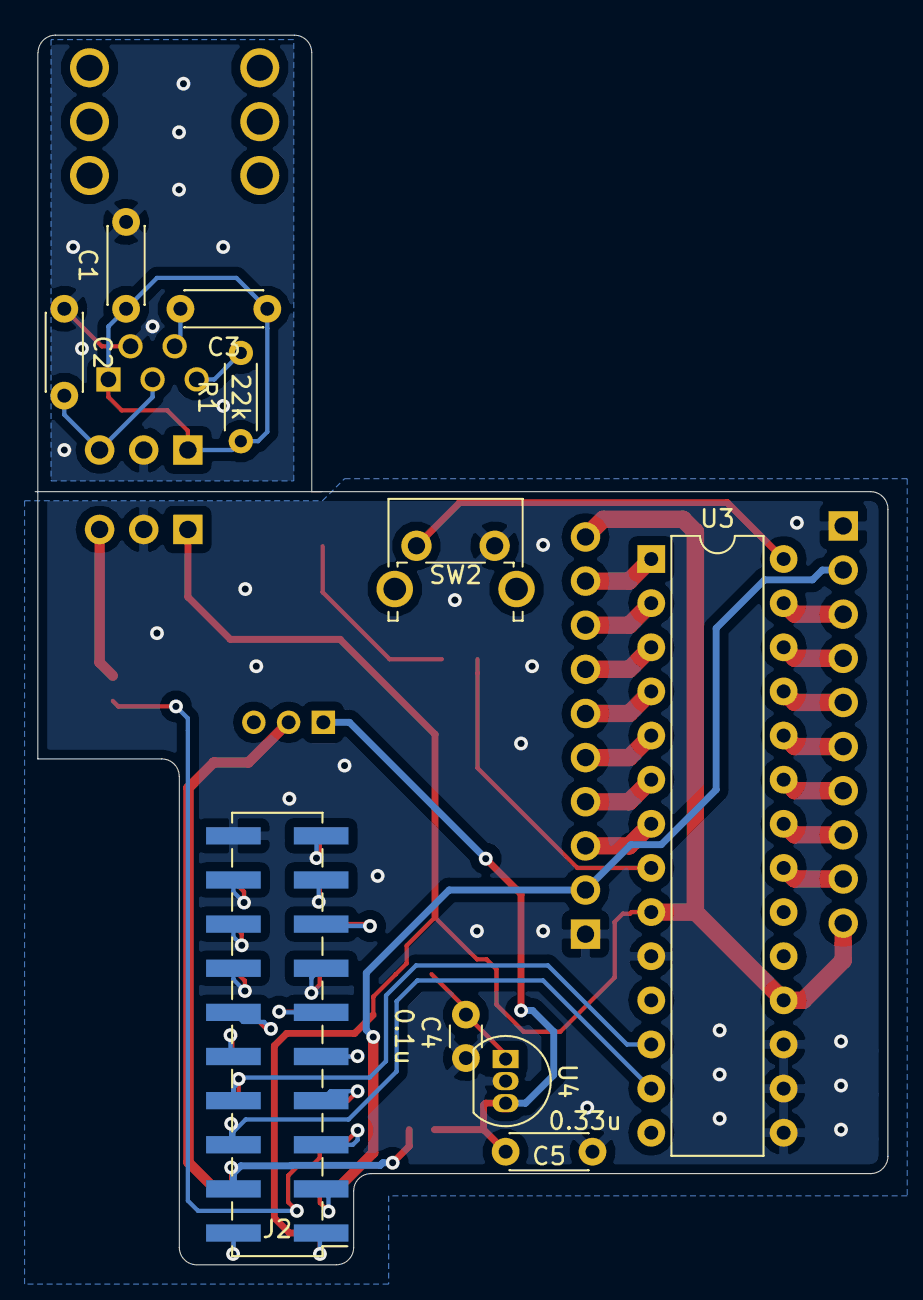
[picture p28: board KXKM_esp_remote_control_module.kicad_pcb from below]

Board: 2 copper layers, 48.9 x 70.8 mm, 22 parts (10 on the bottom side), 45 nets.

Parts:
C1, C3: 47n; C_Disc_D4.3mm_W1.9mm_P5.00mm
C2: 4.7n; C_Disc_D4.3mm_W1.9mm_P5.00mm
C4: 0.1u; C_Disc_D3.0mm_W1.6mm_P2.50mm
C5: 0.33u; C_Disc_D4.3mm_W1.9mm_P5.00mm
D1: LED; LED_0805_2012Metric_Pad1.15x1.40mm_HandSolder
D2: DIODE; D_0805_2012Metric_Pad1.15x1.40mm_HandSolder
J1, J6: Conn_01x03; PinHeader_1x03_P2.54mm_Vertical
J2: Conn_02x10_Odd_Even; PinHeader_2x10_P2.54mm_Vertical_SMD
J3: Conn_02x10_Odd_Even; PinSocket_2x10_P2.54mm_Vertical_SMD
J4: GPIOB_conn; PinHeader_1x10_P2.54mm_Vertical
J5: GPIOA_conn; PinHeader_1x10_P2.54mm_Vertical
JP1, JP2: Solder_Open; SolderJumper-2_P1.3mm_Open_TrianglePad1.0x1.5mm
R1: 22k; R_Axial_DIN0204_L3.6mm_D1.6mm_P5.08mm_Horizontal
R2: 220; R_0805_2012Metric_Pad1.15x1.40mm_HandSolder
SW1: SW_SPDT; Sw_MFS101D-10_1x03_P2.00mm
SW2: SW_Push; SW_Tactile_SPST_Angled_PTS645Vx58-2LFS
U1: HO10P-P-SP33; HO10PSP33
U3: MCP23017_SP; DIP-28_W7.62mm
U4: L78L33_TO92; TO-92_Inline

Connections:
+3V3: D2.2, J1.1, J2.1, J3.1, J4.10, J5.10, U3.9, U3.18
+BATT: J2.4, J3.4, JP1.1, SW1.2
+VSW: J2.2, J3.2
/A0: J5.9, U3.21
/A1: J5.8, U3.22
/A2: J5.7, U3.23
/A3: J5.6, U3.24
/A4: J5.5, U3.25
/A5: J5.4, U3.26
/A6: J5.3, U3.27
/A7: SW2.1, U3.28
/ADC: J2.5, J3.5, JP2.2
/B0: J4.9, U3.1
/B1: J4.8, U3.2
/B2: J4.7, U3.3
/B3: J4.6, U3.4
/B4: J4.5, U3.5
/B5: J4.4, U3.6
/B6: J4.3, U3.7
/B7: R2.2, U3.8
/DMX_DE: J2.15, J3.15
/DMX_DI: J2.17, J3.17
/DMX_RO: J2.19, J3.19
/I2C_SCL: J2.8, J3.8, U3.12
/I2C_SDA: J2.6, J3.6, U3.13
/I2S_BCK: J2.14, J3.14
/I2S_DATA: J2.12, J3.12
/I2S_LRCK: J2.10, J3.10
/LED_D1: J2.16, J3.16
/LED_D2: J2.18, J3.18
/SPI_CS: J2.13, J3.13
/SPI_MISO: J2.9, J3.9
/SPI_MOSI: J2.11, J3.11
/SPI_SCK: J2.7, J3.7
/ext_3.3: C1.1, C3.1, J6.1, R1.1, U1.1
/ext_gnd: C1.2, C2.1, J6.2, U1.2
/ho10_out: C2.2, J6.3, U1.3
GND: C4.2, C5.2, D1.1, J1.2, J2.20, J3.20, J4.1, J5.1, SW2.2, U3.10, U3.15, U3.16, U3.17, U4.2
unnamed: C3.2, U1.4
unnamed: C4.1, D2.1, U4.1
unnamed: C5.1, JP1.2, SW1.1, U4.3
unnamed: D1.2, R2.1
unnamed: J1.3, JP2.1
unnamed: R1.2, U1.5
VBUS: J2.3, J3.3, J4.2, J5.2

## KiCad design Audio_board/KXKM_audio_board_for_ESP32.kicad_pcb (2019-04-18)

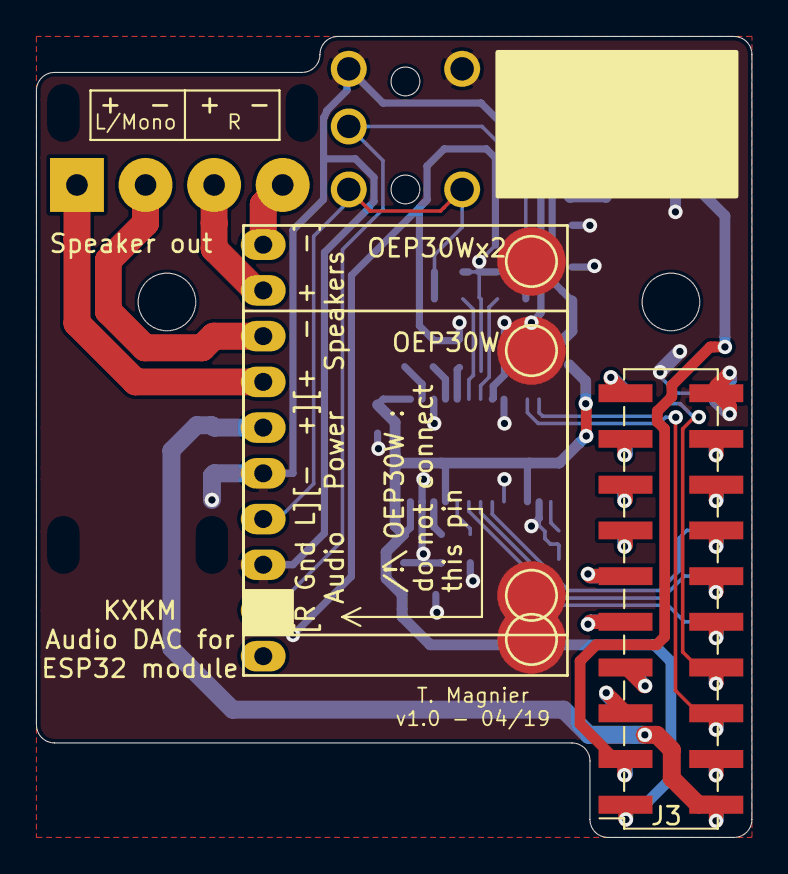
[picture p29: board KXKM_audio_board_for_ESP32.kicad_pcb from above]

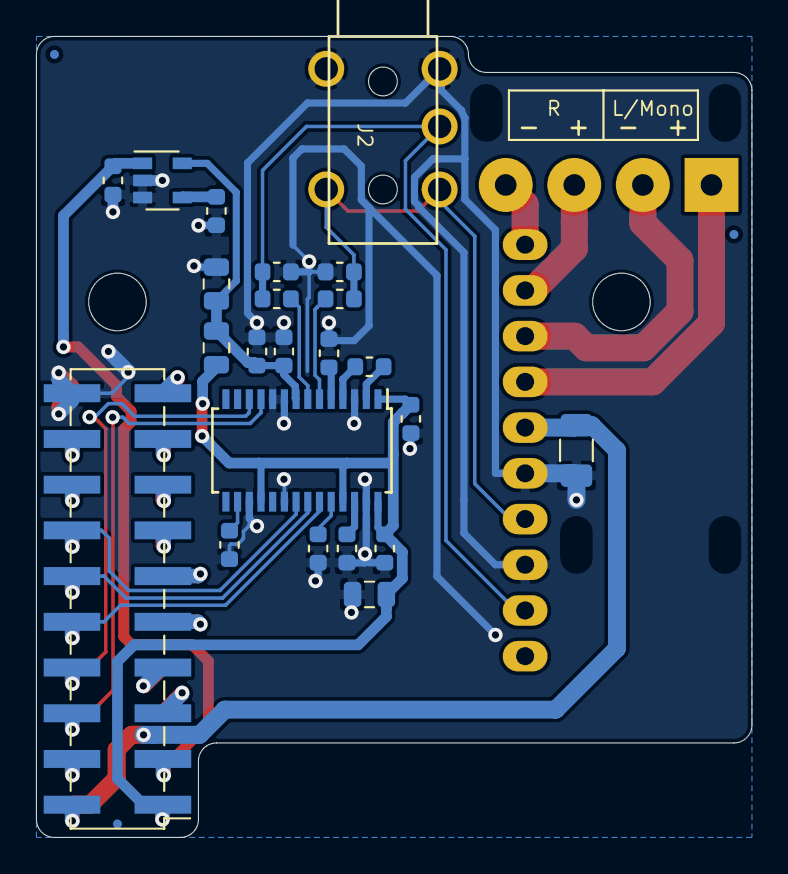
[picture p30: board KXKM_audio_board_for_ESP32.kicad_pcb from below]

Board: 2 copper layers, 39.8 x 44.5 mm, 32 parts (26 on the bottom side), 36 nets.

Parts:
C1, C6, C7, C8, C11: 0.1uF; C_0603_1608Metric
C2: 10nF; C_0603_1608Metric
C3, C5: 10uF; C_0805_2012Metric
C4: 1uF; C_0603_1608Metric
C9, C10: 2.2uF/25V; C_0603_1608Metric
C12, C13: 2.2nF/C0G; C_0603_1608Metric
C14: 10uF/50V; C_1206_3216Metric
FB1: Ferrite/60R/3A; L_0805_2012Metric
FID1, FID2, FID3: Fiducial; Fiducial_0.5mm_Mask1mm
H1, H2: MountingHole; MountingHole_3.2mm_M3
J1: Conn_02x10_Odd_Even; PinHeader_2x10_P2.54mm_Vertical_SMD
J2: AudioJack2_Ground; Jack_3.5mm_stereo_PJ-313D
J3: Conn_02x10_Odd_Even; PinSocket_2x10_P2.54mm_Vertical_SMD
J4: Conn_01x04; SolderWirePad_1x04_P3.81mm_Drill1.2mm
R1, R2: 470R/1%; R_0603_1608Metric
R3, R4: 10k; R_0603_1608Metric
U1: DNP/TPS79133DBVR; SOT-23-5
U2: PCM5121; TSSOP-28_4.4x9.7mm_P0.65mm
U3: Audio_amp_OEP30W
U4: Audio_amp_OEP30Wx2

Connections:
+3.3VA: C4.1, C5.1, C7.1, FB1.1, U1.5, U2.8
+3V3: C3.1, C6.1, C8.1, FB1.2, J1.1, J3.1, U2.1, U2.18, U2.25, U2.28
+BATT: J1.4, J3.4
+VSW: C14.1, J1.2, J3.2, U4.5
/ADC: J1.5, J3.5
/Audio/ADDR_1: R3.1, U2.24
/Audio/ADDR_2: R4.1, U2.16
/Audio/AUDIO_L: C13.1, J2.T, R1.1, U4.7
/Audio/AUDIO_R: C12.1, J2.S, R2.1, U4.9
/DMX_DE: J1.15, J3.15
/DMX_DI: J1.17, J3.17
/DMX_RO: J1.19, J3.19
/I2C_SCL: J1.8, J3.8, U2.12
/I2C_SDA: J1.6, J3.6, U2.11
/I2S_BCK: J1.14, J3.14, U2.21
/I2S_DATA: J1.12, J3.12, U2.22
/I2S_LRCK: J1.10, J3.10, U2.23
/LED_D1: J1.16, J3.16
/LED_D2: J1.18, J3.18
/SPI_CS: J1.13, J3.13
/SPI_MISO: J1.9, J3.9
/SPI_MOSI: J1.11, J3.11
/SPI_SCK: J1.7, J3.7
GND: C1.1, C2.1, C3.2, C4.2, C5.2, C6.2, C7.2, C8.2, C10.2, C11.2, C12.2, C13.2, C14.2, J1.20, J2.G, J3.20, R3.2, R4.2, U1.2, U1.3, U2.3, U2.9, U2.10, U2.17, U2.20, U2.27, U3.4, U4.6, U4.8
unnamed: C2.2, U1.4
unnamed: C9.1, U2.2
unnamed: C9.2, U2.4
unnamed: C10.1, U2.5
unnamed: C11.1, U2.26
unnamed: J4.1, U4.4
unnamed: J4.2, U4.3
unnamed: J4.3, U4.2
unnamed: J4.4, U4.1
unnamed: R1.2, U2.6
unnamed: R2.2, U2.7
VBUS: C1.2, J1.3, J3.3, U1.1

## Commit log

2018-03-09 Initial commit - Schematic and footprint association done, sub modules routed
    [KXKM_audio_battery_module.kicad_pcb, KXKM_audio_battery_module.sch, audio.sch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]
2018-03-12 Component placement WIP - multiple Hammond enclosures drawn
    [KXKM_audio_battery_module.kicad_pcb, KXKM_audio_battery_module.sch, battery_monitoring.sch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]
2018-03-13 Almost all components placed... Saving before mirroring everything
    [KXKM_audio_battery_module.kicad_pcb, KXKM_audio_battery_module.sch, audio.sch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]
2018-03-23 v1.0 Add 3D files with Hammond enclosures fabrication outputs
    [1593K.stp, 1593L.stp, 1593X.stp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]
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2018-03-30 v1.1 - changed some resistor values ; manufacturability improvements (thermal relief) ; added a test point for ESP32_EN
    [KXKM_audio_battery_module-B.Cu.gbl, KXKM_audio_battery_module-B.Mask.gbs, KXKM_audio_battery_module-B.Paste.gbp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]
2018-03-30 Update BOM & fab files
    [KXKM_audio_battery_module.kicad_pcb, KXKM_audio_battery_module.sch, KXKM_audio_battery_module_BOM.ods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]
2018-04-19 Final fabrication files for v1.1
    [KXKM_audio_battery_module.kicad_pcb, KXKM_audio_battery_module_BOM.ods]
2018-10-30 Open project with KiCAD v5.0
    [KXKM_audio_battery_module-2018-10-30-11-45-20.sch, KXKM_audio_battery_module-2018-10-30-17-37-25.sch, KXKM_audio_battery_module.kicad_pcb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]
2019-04-16 v2.0 - audio circuitry on a separate board ; optimized connectors and lots of improvements
    [1593K.stp, 1593L.stp, 1593X.stp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]
2019-04-16 Repository cleanup and add audio board project files
    [KXKM_ESP32_battery_management_board-B_Cu.gbl, KXKM_ESP32_battery_management_board-B_Mask.gbs, KXKM_ESP32_battery_management_board-B_Paste.gbp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]
2019-04-18 Fix older symbols assignation
    [KXKM_ESP32_battery_management_board.sch, battery_monitoring.sch, power.sch]
2019-04-18 Fix component values > pick n place convention
    [KXKM_ESP32_battery_management_board.kicad_pcb, KXKM_audio_board_for_ESP32.kicad_pcb, KXKM_audio_board_for_ESP32.sch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]
2020-02-26 Add Remote control board
    [KXKM_esp_remote_control_module.kicad_pcb, KXKM_esp_remote_control_module.sch]
2020-02-26 Add Gerbers
    [KXKM_esp_remote_control_module-B.Cu.gbl, KXKM_esp_remote_control_module-B.Mask.gbs, KXKM_esp_remote_control_module-B.Paste.gbp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]
2020-02-26 Add Bill Of Material
    [KXKM_esp_remote_control_module.kicad_pcb, KXKM_esp_remote_control_module_BOM.ods]
2020-05-26 update gerber and add current sensor doc
    [KXKM_esp_remote_control_module-B.Cu.gbl, KXKM_esp_remote_control_module-B.Mask.gbs, KXKM_esp_remote_control_module-B.Paste.gbp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]
2021-04-30 Documentation output & JLCPCB BoM
    [KXKM_ESP32_battery_management_board_JLCSMT_BoM.ods]
2021-04-30 First look at v3 : components on top side only. Board area maximised for
    [KXKM_ESP32_battery_management_board.kicad_pcb]
2021-08-26 cleaning and moving components
    [KXKM_ESP32_battery_management_board.kicad_pcb]
2021-08-26 update from schematic
    [KXKM_ESP32_battery_management_board.kicad_pcb]
2021-08-26 rescue from cache
    [KXKM_ESP32_battery_management_board.sch, battery_monitoring.sch, power.sch]
2021-09-03 update, etc
    [KXKM_ESP32_battery_management_board.kicad_pcb, KXKM_ESP32_battery_management_board.sch, battery_monitoring.sch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]
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2021-09-13 clean pre v3.0 - Del gerbers
    [KXKM_ESP32_battery_management_board-B_Cu.gbl, KXKM_ESP32_battery_management_board-B_Mask.gbs, KXKM_ESP32_battery_management_board-B_Paste.gbp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]
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2021-09-16 remove not mounted cmp
    [KXKM_ESP32_battery_management_board_JLCSMT_BoM_v3.0.xls]
2021-09-16 remplace usb and J5
    [KXKM_ESP32_battery_management_board_JLCSMT_BoM_v3.0.xls]
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2021-09-27 follow up of v3.0 to v3.1, no differences (PCB only
    [KXKM_ESP32_battery_management_board_BoM_v3.1.ods, KXKM_ESP32_battery_management_board_JLCSMT_BoM_v3.1.xls]
2021-09-27 fix silkscreen and version on silk
    [KXKM_ESP32_battery_management_board-B_Cu.gbl, KXKM_ESP32_battery_management_board-B_Mask.gbs, KXKM_ESP32_battery_management_board-B_Paste.gbp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]
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2022-07-11 Rangement BaseBoard par version
    [KXKM_ESP32_battery_management_board-B_Cu.gbl, KXKM_ESP32_battery_management_board-B_Mask.gbs, KXKM_ESP32_battery_management_board-B_Paste.gbp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]
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2023-09-07 update v3.2
    - connecteur XT60 coudé (et disponible chez JLCPCB)
    - modification de l’autoboot pour un redémarrage en cas de perte brêve d’alimentation,
    - ajout de l’empreinte pour rajouter une lecteur microSD
    - mise à jour des piste de sortie batterie conforme pour 10A
    - suppression des pin I2C (déjà dispo sur le GPIO)
    - connecteur JST B3B-EH pour un câblage et éviter les soudure qui casse sur les sortie pour LED
    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
    [KXKM_ESP32_battery_management_board-B_Cu.gbl, KXKM_ESP32_battery_management_board-B_Mask.gbs, KXKM_ESP32_battery_management_board-B_Paste.gbp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]
2023-09-07 add freecad file
    add freecad file for casing with cut for CNC
    [1593K.igs, 1593K.stp, casing.FCStd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]
2023-09-07 update casing
    better file naming
    [1593K.igs, 1593K.stp, KXKM_ESP32_Casing Hammond_1593KBK.FCStd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]
2023-10-11 update to v3.2 and casing 3D View
    [KXKM_ESP32_Casing Hammond_1593KBK 3.FCStd, KXKM_ESP32_Casing Hammond_1593KBK.FCStd, KXKM_ESP32_battery_management_board.kicad_pcb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]
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2026-03-10 feat(hardware): commit battery board schematic and symbol table updates
    Isolate electrical and KiCad project deltas from prior hygiene cleanup to keep hardware review focused.
    [KXKM_ESP32_battery_management_board.kicad_sch, battery_monitoring.kicad_sch, power.kicad_sch]
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
